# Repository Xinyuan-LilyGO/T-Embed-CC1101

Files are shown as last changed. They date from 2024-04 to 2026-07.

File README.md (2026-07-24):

<h1 align = "center">🏆T-Embed-CC1101🏆</h1>

* [切换到中文](./README_CN.md)



<p> 
  
  
  
</p>

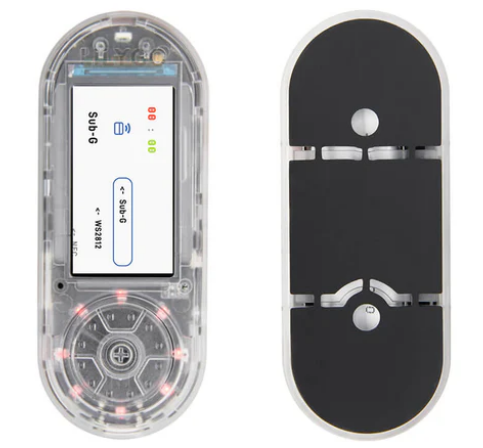
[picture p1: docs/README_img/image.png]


## :zero: Version 🎁

### 1、Latest version
- Software : v1.3-250822
- Hardware : v1.0-241103

### 2、Where to buy.
[LilyGo Store](https://www.lilygo.cc/products/t-embed-cc1101)

## :one: Product 🎁

Video about T-Embed-CC1101 :  [youtube](https://www.youtube.com/watch?v=U06XI1wtp4U) 

| Product | [T-Embed-CC1101 ](https://www.lilygo.cc/products/t-embed-cc1101) |
| :---: | :---: |
| MCU | ESP32-S3-WROOM-1 |
|  Flash / PSRAM | 16M / 8M |
| Sub-G | CC1101 |
| NFC | PN532 (0x24) |
| Display IC | ST7789 (320x170) |
| Battery Capacity | 3.7V-1300mAh |
| Battery Chip | BQ25896 (0x6B), BQ27220 (0x55) |
| LED Driver | WS2812 |

The charging current should ideally not exceed half of the battery capacity, and for the `T-Embed-CC1101`, it should not exceed `600mA`

External antenna 2.4G gains 1.5dBi, Sub1G antenna gain: -0.57dBi

Expansion module:

| - | NRF24 |
| :--- | :--- |
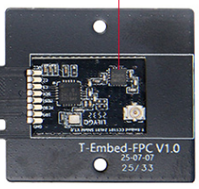
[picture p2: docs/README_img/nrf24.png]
| Module style |  |
| PIN | CS --- 44  <br>CE --- 43 <br>MOSI --- 9<br>MISO --- 10<br>SCK --- 11 |
| examples | [click me](./examples/extend_nrf2401) |

➡ Some interesting projects that support T-Embed-CC1101：

| name | code | web |
|:---:| :---: | :---: |
| Flipper Zero | [github](https://github.com/Sor3nt/Flipper-Zero-ESP32-Port "https://github.com/Sor3nt/Flipper-Zero-ESP32-Port") | [web](https://sor3nt.github.io/interface.html "https://sor3nt.github.io/interface.html") |
| Bruce | [github](https://github.com/pr3y/Bruce/tree/WebPage "https://github.com/pr3y/Bruce/tree/WebPage") | [web](https://bruce.computer/flasher.html "https://bruce.computer/flasher.html") |
| Launcher | [github](https://github.com/bmorcelli/M5Stick-Launcher.git "https://github.com/bmorcelli/M5Stick-Launcher.git") | [web](https://bmorcelli.github.io/Launcher/catalog.html) |
| CapibaraZero | [github](https://github.com/CapibaraZero/fw.git "https://github.com/CapibaraZero/fw.git") | [web](https://capibarazero.com/docs/esp32_s3/boards/LilyGo_T_Embed_CC1101) |

## :two: Module 🎁

Datasheets on the chip are available in [./hardware](./hardware/) directory.

| Name | Dependency library |
| :---: | :---: |
|  CC1101  | [jgromes/RadioLib@6.5.0](https://github.com/jgromes/RadioLib) |
|  PN532 | https://github.com/Seeed-Studio/PN532.git |
| BQ25896  | [lewisxhe/XPowersLib@^0.2.3](https://github.com/lewisxhe/XPowersLib) |
|  ST7789  | [bodmer/TFT_eSPI@^2.5.43](https://github.com/Bodmer/TFT_eSPI) |
|  Encode  | [mathertel/RotaryEncoder@^1.5.3](http://www.mathertel.de/Arduino/RotaryEncoderLibrary.aspx) |
|  WS2812  | [fastled/FastLED@^3.9.12](https://github.com/FastLED/FastLED) |
| Infrared | [crankyoldgit/IRremoteESP8266@^2.8.6](https://github.com/crankyoldgit/IRremoteESP8266) |
|  Audio | [esphome/ESP32-audioI2S@2.0.0](https://github.com/schreibfaul1/ESP32-audioI2S) |
| LVGL | [lvgl/lvgl@^8.3.11](https://github.com/lvgl/lvgl/tree/v8.3.11) |
### 1、Wireless transceiver：

T-Embed-CC1101 has a built-in Sub-GHz module based on a `CC1101` transceiver and a radio antenna (the maximum range is 50 meters).  Both the CC1101 chip and the antenna are designed to operate at frequencies in the 300-348 MHz, 387-464 MHz, and 779-928 MHz bands.

The Sub-GHz application supports external radio modules based on the CC1101 transceiver.

Notice : The frequency selection of CC1101 is configured through `SW0` and `SW1`.
~~~c
// SW1:1  SW0:0 --- 315MHz
// SW1:0  SW0:1 --- 868/915MHz
// SW1:1  SW0:1 --- 434MHz
#define BOARD_LORA_SW1  47
#define BOARD_LORA_SW0  48
~~~
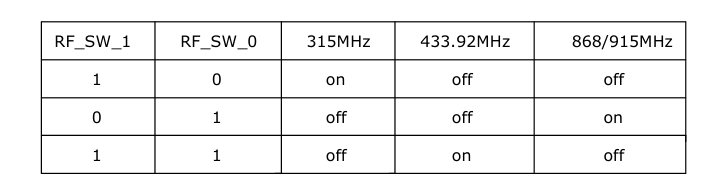
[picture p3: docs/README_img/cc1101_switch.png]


### 2、PN532

The PN532 only supports high-frequency cards at 13.56MHz, does not support low-frequency cards at 125K, does not support CPU cards, and does not support encryption cards.

"✅" represents a card of support.
| **Type** | **Encryption Method** | **Anti-Copy Capability** | **Attack Risk** | Typical uses |
| :---: | :---: | :---: | :---: | :---: |
| **Mifare Classic** ✅ | Weak (CRYPTO1 algorithm, cracked) | Low | Easily cloned (e.g., via Proxmark3 tools) | Access control cards, public transportation cards (old system) |
| **NTAG**  ✅ | No encryption (UID lockable) | Very Low | Data can be arbitrarily read | Smart labels, advertising interaction, and product anti-counterfeiting |
| **Mifare Plus** | AES-128 encryption | Medium-High | Requires physical access to crack | - |
| **Felica** |  Dynamic encryption (SAM module)  | High | Hard to crack (Japan-exclusive protocol) | Japanese transportation cards, electronic wallets |
| **DESFire** | AES/TDES encryption | Very High | Supports multi-app isolation, resists side-channel attacks | High-security access control, campus one-card, electronic passport |
| **CPU Card** | Hardware encryption (SM4/ECC/RSA) | Very High | Supports China's national cryptographic standards, financial-grade security | Bank card, ID card, social security card |

## :three: Quick Start 🎁

🟢 PlatformIO is recommended because these examples were developed on it. 🟢 

### 1、PlatformIO

1. Install [Visual Studio Code](https://code.visualstudio.com/) and [Python](https://www.python.org/), and clone or download the project;
2. Search for the `PlatformIO` plugin in the `VisualStudioCode` extension and install it;
3. After the installation is complete, you need to restart `VisualStudioCode`
4. After opening this project, PlatformIO will automatically download the required tripartite libraries and dependencies, the first time this process is relatively long, please wait patiently;
5. After all the dependencies are installed, you can open the `platformio.ini` configuration file, uncomment in `example` to select a routine, and then press `ctrl+s` to save the `.ini` configuration file;
6. Click :ballot_box_with_check: under VScode to compile the project, then plug in USB and select COM under VScode;
7. Finally, click the :arrow_right:  button to download the program to Flash;

### 2、Arduino IDE

1. Install [Arduino IDE](https://www.arduino.cc/en/software)

2. Copy all files under `this project/lib/` and paste them into the Arduion library path (generally `C:\Users\YourName\Documents\Arduino\libraries`);

3. Open the Arduion IDE and click `File->Open` in the upper left corner to open an example in `this project/example/xxx/xxx.ino` under this item;

4. Then configure Arduion. After the configuration is completed in the following way, you can click the button in the upper left corner of Arduion to compile and download;

| Arduino IDE Setting | Value |
| --- | --- |
| Board | **ESP32S3 Dev Module** |
| Port | Your port |
| USB CDC On Boot | Enable |
| CPU Frequency | 240MHZ(WiFi) |
| Core Debug Level | None |
| USB DFU On Boot | Disable |
| Erase All Flash Before Sketch Upload | Disable |
| Events Run On | Core1 |
| Flash Mode | QIO 80MHZ |
| Flash Size | **16MB(128Mb)** |
| Arduino Runs On | Core1 |
| USB Firmware MSC On Boot | Disable |
| Partition Scheme | **16M Flash(3M APP/9.9MB FATFS)** |
| PSRAM | **OPI PSRAM** |
| Upload Mode | **UART0/Hardware CDC** |
| Upload Speed | 921600 |
| USB Mode | **CDC and JTAG** |

### 3、Folder structure:
~~~
├─3D_files: Store 3D structure files
├─boards  : Some information about the board for the platformio.ini configuration project;
├─data    : Picture resources used by the program;
├─example : Some examples;
├─firmare : `factory` compiled firmware;
├─hardware: Schematic diagram of the board, chip data;
├─lib     : Libraries used in the project;
~~~

### 4、Examples

~~~
- ✅ bq27xxx_test : BQ27220 test.
- ✅ bq25896_test : Battery management test. Print the battery status in the serial port.
- ✅ cc1101_recv_irq ：Wireless reception test, display received messages in the serial port.
- ✅ cc1101_send_irq ：Wireless sending test, display sent messages in the serial port.
- ✅ display_test ：Screen display test;
- ✅ encode_test ：encoder tester
- ✅ factory_test ：Factory programs can currently only be compiled and downloaded on PlatformIO;
- ✅ infrared_recv_test: Infrared test
- ✅ infrared_send_test: Infrared test
- ✅ lvgl_test ：lvgl benchmark and stress testing;
- ✅ pn532_test ：NFC test, display the IC card information in the serial port.
- ✅ tf_card_test ：SD card test, the file name is displayed in the serial port.
- ✅ record_test : Record 15 seconds of audio and save it to your SD card.
- ✅ voice_test : Loudspeaker test, read audio from SPIFFS.
- ✅ ble_uart_pairing : BLE UART pairing/status demo with on-screen passkey, bonding, connection state, and text echo. This is BLE GATT UART, not A2DP audio.
- ✅ ws2812_test ：LED light test;
~~~

## :four: Pins 🎁

~~~c
#define BOARD_USER_KEY 6
#define BOARD_PWR_EN   15

// WS2812
#define WS2812_NUM_LEDS 8
#define WS2812_DATA_PIN 14

// IR
#define BOARD_IR_EN 2
#define BOARD_IR_RX 1

// MIC
#define BOARD_MIC_DATA 42
#define BOARD_MIC_CLK  39

// VOICE
#define BOARD_VOICE_BCLK  46
#define BOARD_VOICE_LRCLK 40
#define BOARD_VOICE_DIN   7

// --------- DISPLAY ---------
// About LCD definition in the file: lib/TFT_eSPI/User_Setups/Setup214_LilyGo_T_Embed_PN532.h
#define DISPLAY_WIDTH  170
#define DISPLAY_HEIGHT 320

#define DISPLAY_BL   21 
#define DISPLAY_CS   41
#define DISPLAY_MISO 10
#define DISPLAY_MOSI  9
#define DISPLAY_SCLK 11
#define DISPLAY_DC   16
#define DISPLAY_RST  -1

// --------- ENCODER ---------
#define ENCODER_INA 4
#define ENCODER_INB 5
#define ENCODER_KEY 0

// --------- IIC ---------
#define BOARD_I2C_SDA  8
#define BOARD_I2C_SCL  18

// IIC addr
#define BOARD_I2C_ADDR_1 0x24  // PN532
#define BOARD_I2C_ADDR_2 0x55  // BQ27220
#define BOARD_I2C_ADDR_3 0x6b  // BQ25896

// NFC
#define BOARD_PN532_SCL     BOARD_I2C_SCL
#define BOARD_PN532_SDA     BOARD_I2C_SDA
#define BOARD_PN532_RF_REST 45
#define BOARD_PN532_IRQ     17

// --------- SPI ---------
#define BOARD_SPI_SCK  11
#define BOARD_SPI_MOSI 9
#define BOARD_SPI_MISO 10

// TF card
#define BOARD_SD_CS   13
#define BOARD_SD_SCK  BOARD_SPI_SCK
#define BOARD_SD_MOSI BOARD_SPI_MOSI
#define BOARD_SD_MISO BOARD_SPI_MISO

// LORA
#define BOARD_LORA_CS   12
#define BOARD_LORA_SCK  BOARD_SPI_SCK
#define BOARD_LORA_MOSI BOARD_SPI_MOSI
#define BOARD_LORA_MISO BOARD_SPI_MISO
#define BOARD_LORA_IO2  38
#define BOARD_LORA_IO0  3
#define BOARD_LORA_SW1  47
#define BOARD_LORA_SW0  48
~~~

### Extension interface

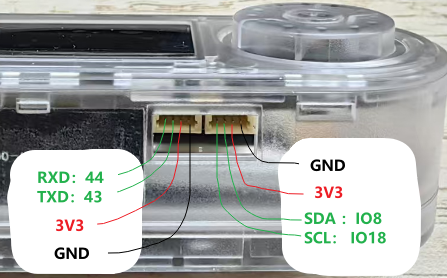
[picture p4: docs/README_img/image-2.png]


## :five: Test 🎁

Sleep power consumption.

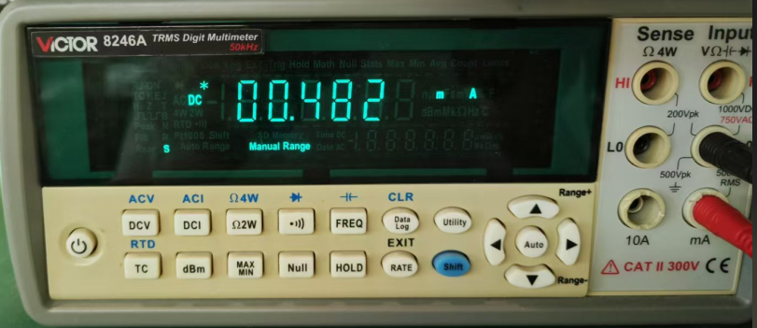
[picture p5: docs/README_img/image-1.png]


## :six: FAQ 🎁

### Unable to detect sd card：
We were able to successfully test SD with SanDisk no larger than 32GB; But some other cards don't, and it's not clear why;

Therefore, when the SD card is not detected, it is recommended to change a SanDisk card not larger than 32G;

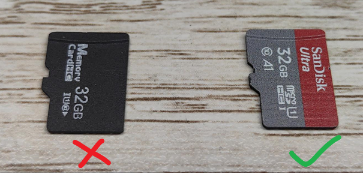
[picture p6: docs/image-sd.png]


### Other questions

| Problem | Link |
| :---: | :---: |
| How do I enter download mode? | [docs](./docs/download_mode.md) |
| How to download the program? | [dosc](./docs/flash_download_tool.md) |
|  How do I turn on the device after I shut it down?  | [Issues #5](https://github.com/Xinyuan-LilyGO/T-Embed-CC1101/issues/5) |
|      How do I configure Wifi with EspTouch?         | [Issues #4](https://github.com/Xinyuan-LilyGO/T-Embed-CC1101/issues/4) |
| Why won't the battery charge？ | [Issues #9](https://github.com/Xinyuan-LilyGO/T-Embed-CC1101/issues/9) |
| no display on the screen | [dosc](./docs/issue.md) |

## :seven: Schematic & 3D 🎁

For more information, see the `./hardware` directory.

Schematic : [T-Embed-CC1101](./hardware/T-Embed-CC1101%20V1.0%2024-07-29.pdf)

CC1101 Schematic : [CC1101](./hardware/cc1101-shield.pdf)

CC1101 Pins : [CC1101 Pins](./hardware/CC1101_pin.png)

3D Files : [T-Embed CC1101.stp](./3D_files)

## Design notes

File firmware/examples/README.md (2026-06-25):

# [中文](./README_CN.md) | English

# `firmware/examples/` Usage Guide

The `firmware/examples/` directory stores flashable example firmware generated from `examples/`.

Each build now exports only one merged `.bin` file directly into this directory. A typical structure looks like this:

```text
firmware/examples/
  README.md
  README_CN.md
  factory.bin
  test_ir_send_recv.bin
  test_cc1101_send_recv.bin
```

## 1. Which file should I use

Use the example-named `.bin` file directly, for example:

- `factory.bin`
- `test_ir_send_recv.bin`
- `test_cc1101_send_recv.bin`

Each file is a fully merged firmware image and should be flashed at address `0x0`.

## 2. How to flash

Example:

```powershell
python script\esptool.py --chip esp32s3 --baud 921600 write_flash -z 0x0 firmware\examples\test_ir_send_recv.bin
```

If `esptool` is already installed on your system, you can also use `esptool.py` directly or `python -m esptool`.

## 3. How to switch to another example

To test another example, flash that example's `.bin` file from `firmware/examples/`.

Examples:

- IR example: `firmware/examples/test_ir_send_recv.bin`
- CC1101 example: `firmware/examples/test_cc1101_send_recv.bin`
- Battery example: `firmware/examples/test_battery_bq27220_bq25896.bin`

## 4. Notes

- Make sure the device is in a downloadable state and the USB/serial connection is working before flashing.
- These firmware files are generated for this project's hardware configuration and should not be assumed to work on other boards.
- Some test examples are intended to be used together with serial logs, such as IR, wireless, battery, or NFC-related tests.
- Rebuilding the same example overwrites `firmware/examples/<example>.bin`.
- If an example path contains subfolders, the output filename uses `__` in place of `/`.
  For example, `extend_nrf2401/recv` becomes `extend_nrf2401__recv.bin`.

## 5. How to regenerate these files

Use the build script from the project root:

```powershell
python script\build_example_firmware.py --list
python script\build_example_firmware.py test_ir_send_recv
python script\build_example_firmware.py test_ir_send_recv test_cc1101_send_recv
python script\build_example_firmware.py --all
```

After the build completes, the generated `.bin` files will be placed in `firmware/examples/`.

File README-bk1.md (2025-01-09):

<h1 align = "center">🏆T-Embed-CC1101🏆</h1>



<p> 
  
  
  
</p>

<!-- * [切换到中文版](./README_CN.md) -->

## :zero: Troubleshooting

Video about T-Embed-CC1101 :  [youtube](https://www.youtube.com/watch?v=U06XI1wtp4U) 

| Problem | Link |
| :---: | :---: |
| How do I enter download mode? | [docs](./docs/download_mode.md) |
| How to download the program? | [dosc](./docs/flash_download_tool.md) |
|  How do I turn on the device after I shut it down?  | [Issues #5](https://github.com/Xinyuan-LilyGO/T-Embed-CC1101/issues/5) |
|      How do I configure Wifi with EspTouch?         | [Issues #4](https://github.com/Xinyuan-LilyGO/T-Embed-CC1101/issues/4) |
| Why won't the battery charge？ | [Issues #9](https://github.com/Xinyuan-LilyGO/T-Embed-CC1101/issues/9) |

## :one:Product 🎁

| Product | [T-Embed-CC1101 ](https://www.lilygo.cc/products/t-embed-cc1101) |
| :---: | :---: |
| MCU | ESP32-S3-WROOM-1 |
|  Flash / PSRAM | 16M / 8M |
| Sub-G | CC1101 |
| NFC | PN532 |
| Display IC | ST7789 (320x170) |
| Battery Capacity | 3.7V-1300mAh |
| Battery Chip | BQ25896, BQ27220 |
| LED Driver | WS2812 |

### About SD Card：
We were able to successfully test SD with SanDisk no larger than 32GB; But some other cards don't, and it's not clear why;

Therefore, when the SD card is not detected, it is recommended to change a SanDisk card not larger than 32G;



### Wireless transceiver：

T-Embed-CC1101 has a built-in Sub-GHz module based on a `CC1101` transceiver and a radio antenna (the maximum range is 50 meters). Both the CC1101 chip and the antenna are designed to operate at frequencies in the 300-348 MHz, 387-464 MHz, and 779-928 MHz bands.

The Sub-GHz application supports external radio modules based on the CC1101 transceiver.

### Folder structure:
~~~
├─boards  : Some information about the board for the platformio.ini configuration project;
├─data    : Picture resources used by the program;
├─example : Some examples;
├─firmare : `factory` compiled firmware;
├─hardware: Schematic diagram of the board, chip data;
├─lib     : Libraries used in the project;
~~~

## :two: Example 🎯

Some examples are provided under the Project example folder, which can run on PlatformIO (PIO) and Arduion, but I prefer to use PIO because these examples are developed on PIO, **All examples can run on PIO**, However, you may encounter compilation errors on Arduion, but don't worry, the author will step up to test the compilation of Arduion environment.

**Examples of compilation in Arduion environment:**

- ✅ bq25896_test : Battery management test. Print the battery status in the serial port.
- ✅ cc1101_recv_irq ：Wireless reception test, display received messages in the serial port.
- ✅ cc1101_send_irq ：Wireless sending test, display sent messages in the serial port.
- ✅ display_test ：Screen display test;
- ✅ encode_test ：encoder tester
- ❌ factory_test ：Factory programs can currently only be compiled and downloaded on PlatformIO;
- ✅ infrared_recv_test: Infrared test
- ✅ infrared_send_test: Infrared test
- ✅ lvgl_test ：lvgl benchmark and stress testing;
- ✅ pn532_test ：NFC test, display the IC card information in the serial port.
- ✅ tf_card_test ：SD card test, the file name is displayed in the serial port.
- ✅ record_test : Record 15 seconds of audio and save it to your SD card.
- ✅ voice_test : Speaker test, read audio from SD card.
- ✅ ws2812_test ：LED light test;

## :three: PlatformIO Quick Start

1. Install [Visual Studio Code](https://code.visualstudio.com/) and [Python](https://www.python.org/), and clone or download the project;
2. Search for the `PlatformIO` plugin in the `VisualStudioCode` extension and install it;
3. After the installation is complete, you need to restart `VisualStudioCode`
4. After opening this project, PlatformIO will automatically download the required tripartite libraries and dependencies, the first time this process is relatively long, please wait patiently;
5. After all the dependencies are installed, you can open the `platformio.ini` configuration file, uncomment in `example` to select a routine, and then press `ctrl+s` to save the `.ini` configuration file;
6. Click :ballot_box_with_check: under VScode to compile the project, then plug in USB and select COM under VScode;
7. Finally, click the :arrow_right:  button to download the program to Flash;

## :four: Arduion Quick Start

:exclamation: :exclamation: :exclamation: <font color="red"> **Notice:**</font>
PlatformIO is more recommended because it may not be compiled with Arduion. You can refer to **2️⃣-Example** to see which examples are successfully compiled in Arduion environment.

1. Install [Arduino IDE](https://www.arduino.cc/en/software)
2. Install the esp32 toolkit, open the Arduion IDE, click on `File->Perferences`, Then `https://espressif.github.io/arduino-esp32/package_esp32_index.json ` paste to the position of the diagram below, then click :ok:, waiting for the toolkit download is complete;

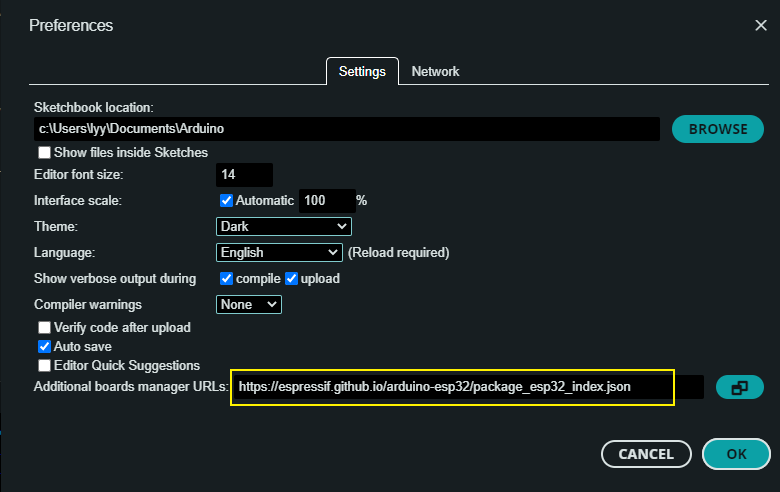
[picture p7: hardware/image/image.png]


3. Copy all files under `this project/lib/` and paste them into the Arduion library path (generally `C:\Users\YourName\Documents\Arduino\libraries`);
4. Open the Arduion IDE and click `File->Open` in the upper left corner to open an example in `this project/example/xxx/xxx.ino` under this item;
5. Then configure Arduion. After the configuration is completed in the following way, you can click the button in the upper left corner of Arduion to compile and download;

| Arduino IDE Setting | Value |
| --- | --- |
| Board | **ESP32S3 Dev Module** |
| Port | Your port |
| USB CDC On Boot | Enable |
| CPU Frequency | 240MHZ(WiFi) |
| Core Debug Level | None |
| USB DFU On Boot | Disable |
| Erase All Flash Before Sketch Upload | Disable |
| Events Run On | Core1 |
| Flash Mode | QIO 80MHZ |
| Flash Size | **16MB(128Mb)** |
| Arduino Runs On | Core1 |
| USB Firmware MSC On Boot | Disable |
| Partition Scheme | **16M Flash(3M APP/9.9MB FATFS)** |
| PSRAM | **OPI PSRAM** |
| Upload Mode | **UART0/Hardware CDC** |
| Upload Speed | 921600 |
| USB Mode | **CDC and JTAG** |

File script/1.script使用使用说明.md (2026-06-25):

# 自动打包工具

- **pos_extra_script.py** 将编译生成的 boot.bin、bootload.bin、partition.bin 打包生成一个 bin 文件；

应用举例：在 platformIO 的环境中，找到 platformio.ini 配置文件，在配置文件关于工程的默认环境下，添加该脚本，如下：

~~~
...

[env]
platform = espressif32@6.3.0
framework = arduino
upload_speed = 115200
...
extra_scripts =  ./script/pos_extra_script.py
...
~~~

如上所示，在添加 extra_scripts 后，在编译整个工程，编译完成后会自动调用 pos_extra_script.py 脚本生成 firmware_factory_xxxxxxxx.bin 固件；

如果该工程下还有 data 文件夹，则会自动的把 data 文件识别为 spiffs 文件系统，并将 data 文件夹下的所有文件打包成 spiffs.bin，还会自动生成 partitions.csv 文件；

**pos_extra_script.py 生成的所有文件都会放在 "工程目录/build/" 下面；**

# SPIFFS 文件系统

SPIFFS 是一个用于 SPI NOR flash 设备的嵌入式文件系统，支持磨损均衡、文件系统一致性检查等功能。

- **spiffsgen.py** 文件系统打包脚本

~~~ python
python spiffsgen.py <image_size> <base_dir> <output_file>

参数（必选）说明如下：
image_size：分区大小，用于烧录生成的 SPIFFS 镜像；
base_dir：创建 SPIFFS 镜像的目录；
output_file：SPIFFS 镜像输出文件。
~~~

应用举例：将工程 T-Embed-PN532 文件下的 data 文件打包，生成的 .bin 文件放到 build 文件夹下，则因向命令行输入如下命令：

~~~ python
python spiffsgen.py 0x360000 ..\data\ ..\build\spiffs.bin
~~~

## build_example_firmware

作用是从 `examples/` 里选示例编译，并把可下载的固件文件导出到 `firmware/examples/<示例名>/bin/`。

最常用的几种命令是：

列出所有可构建示例。
~~~powershell
python script\build_example_firmware.py --list
~~~

构建单个示例。
~~~powershell
python script\build_example_firmware.py test_ir_send_recv
~~~

一次构建多个示例。
~~~powershell
python script\build_example_firmware.py test_ir_send_recv test_ws2812
~~~

一次构建 examples/ 下全部示例。
~~~powershell
python script\build_example_firmware.py --all
~~~

可选参数：
~~~powershell
python script\build_example_firmware.py test_ir_send_recv --no-clean
python script\build_example_firmware.py test_ir_send_recv --no-merge
python script\build_example_firmware.py --all --continue-on-error
~~~

参数说明：
- `--no-clean`：跳过构建前清理，加快二次编译
- `--no-merge`：不生成合并后的单文件 bin
- `--continue-on-error`：某个示例失败后继续构建后面的示例
- `--env T_Embed_CC1101`：指定 PlatformIO 环境
- `--chip esp32s3`：指定烧录命令里的芯片型号

构建完成后，输出目录类似：
~~~powershell
firmware\examples\test_ir_send_recv\bin\
~~~

里面通常会有：
- `bootloader.bin`
- `partitions.bin`
- `firmware.bin`
- `test_ir_send_recv.bin` 这是合并后的单文件固件
- `esptool_command.txt`
- `esptool_merged_command.txt`
- `build_info.json`

如果你想直接烧录合并包，可以看对应目录下的 `esptool_merged_command.txt`。
补一句，最好不要同时开两个 `build_example_firmware.py` 进程，因为它们会共用 `.pio/build/T_Embed_CC1101`。

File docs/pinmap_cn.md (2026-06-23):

# T-Embed-CC1101 引脚映射（V1.0 / 2026-06-23）
> 本文根据 `hardware/T-Embed-CC1101 V1.0 24-07-29.pdf`、`README.md`、`README_CN.md`、`examples/factory_test/utilities.h`、`docs/README_img/image-2.png` 整理。
> 仓库里的部分宏名沿用了旧命名：`BOARD_LORA_*` 实际对应板载 `CC1101`，`BOARD_PN532_*` 对应板载 `PN532`。
> 需要先说明：当前仓库里有两处定义不完全一致。其一是个别示例把 I2C `SDA/SCL` 写反；其二是 LCD `RST` 在原理图与软件配置之间存在歧义。文中会单独标注。

## 1. 主控与公共总线

| 功能 | 建议名 | GPIO/映射 | 来源 | 备注 |
| --- | --- | --- | --- | --- |
| 主 I2C SDA | `BOARD_I2C_SDA` | GPIO8 | 原理图 Page 1/2/3/4，`docs/README_img/image-2.png`，`examples/factory_test/utilities.h` | 板载 PN532、BQ27220、BQ25896 与外接 I2C 口共用；`examples/cc1101_recv/utilities.h` 把 SDA/SCL 对调了，建议以本表为准 |
| 主 I2C SCL | `BOARD_I2C_SCL` | GPIO18 | 原理图 Page 1/2/3/4，`docs/README_img/image-2.png`，`examples/factory_test/utilities.h` | 同上 |
| 主 SPI SCK | `BOARD_SPI_SCK` | GPIO11 | 原理图 Page 2/3/4，`examples/factory_test/utilities.h` | LCD、TF、PN532、CC1101、外接 nRF24 共用 |
| 主 SPI MOSI | `BOARD_SPI_MOSI` | GPIO9 | 原理图 Page 2/3/4，`examples/factory_test/utilities.h` | 同上 |
| 主 SPI MISO | `BOARD_SPI_MISO` | GPIO10 | 原理图 Page 2/3/4，`examples/factory_test/utilities.h` | 同上 |
| 开关 3.3 V 使能 | `BOARD_PWR_EN` | GPIO15 | 原理图 Page 1/2，`README.md`，`examples/factory_test/utilities.h` | 控制开关电源域 `VCC3V3`；仓库示例注释明确写到会给 CC1101 与 WS2812/LED 上电 |
| USB D- | `BOARD_USB_DM` | GPIO19 | 原理图 Page 1/2 | Type-C 直连 ESP32-S3 USB |
| USB D+ | `BOARD_USB_DP` | GPIO20 | 原理图 Page 1/2 | Type-C 直连 ESP32-S3 USB |
| 串口调试 TX | `BOARD_UART0_TXD` | `U0TXD` / GPIO43 | 原理图 Page 2，`docs/README_img/image-2.png` | 外接接口图片标成 `TXD: 43`；扩展 nRF24 示例中也把这脚复用为 `CE` |
| 串口调试 RX | `BOARD_UART0_RXD` | `U0RXD` / GPIO44 | 原理图 Page 2，`docs/README_img/image-2.png` | 外接接口图片标成 `RXD: 44`；扩展 nRF24 示例中也把这脚复用为 `CS` |

## 2. 按键与编码器

| 功能 | 建议名 | GPIO/映射 | 来源 | 备注 |
| --- | --- | --- | --- | --- |
| 用户按键 | `BOARD_USER_KEY` | GPIO6 | 原理图 Page 2，`README.md`，`examples/factory_test/utilities.h` | 独立按键 |
| 编码器 A 相 | `ENCODER_INA` | GPIO4 | 原理图 Page 2/4，`examples/factory_test/utilities.h` | 旋钮编码器 A 相 |
| 编码器 B 相 | `ENCODER_INB` | GPIO5 | 原理图 Page 2/4，`examples/factory_test/utilities.h` | 旋钮编码器 B 相 |
| 编码器按压 / BOOT | `ENCODER_KEY` | GPIO0 | 原理图 Page 2/4，`examples/factory_test/utilities.h` | 既是编码器按键又是启动脚，低电平会影响下载/启动模式 |
| 复位按键 | `BOARD_RST_EN` | `EN` | 原理图 Page 2 | 复位按键，不是普通 GPIO |

## 3. 扩展接口与外接模块

| 接口/功能 | 建议名 | 引脚/网络 | 来源 | 备注 |
| --- | --- | --- | --- | --- |
| 外接 UART TX | `BOARD_UART0_TXD` | GPIO43 | 原理图 Page 2，`docs/README_img/image-2.png` | 与 3V3 / GND 一起引出 |
| 外接 UART RX | `BOARD_UART0_RXD` | GPIO44 | 原理图 Page 2，`docs/README_img/image-2.png` | 与 3V3 / GND 一起引出 |
| 外接 I2C SDA | `BOARD_I2C_SDA` | GPIO8 | 原理图 Page 2，`docs/README_img/image-2.png` | 与 3V3 / GND 一起引出 |
| 外接 I2C SCL | `BOARD_I2C_SCL` | GPIO18 | 原理图 Page 2，`docs/README_img/image-2.png` | 与 3V3 / GND 一起引出 |
| 外接 nRF24 CE | `BOARD_NRF24_CE` | GPIO43 | `examples/factory_test/utilities.h`，`examples/extend_nrf2401/*` | 只在外接模块场景使用；与外接 UART `TXD` 复用 |
| 外接 nRF24 CS | `BOARD_NRF24_CS` | GPIO44 | `examples/factory_test/utilities.h`，`examples/extend_nrf2401/*` | 只在外接模块场景使用；与外接 UART `RXD` 复用 |
| 外接 nRF24 SPI | `BOARD_NRF24_SCK/MOSI/MISO` | GPIO11 / 9 / 10 | `examples/factory_test/utilities.h`，`examples/extend_nrf2401/*` | 共享主 SPI |
| 外接 nRF24 IRQ | `BOARD_NRF24_IRQ` | `-1` | `examples/factory_test/utilities.h` | 当前仓库未给外接 nRF24 分配独立中断脚 |

## 4. TF 卡

| 功能 | 建议名 | GPIO | 来源 | 备注 |
| --- | --- | --- | --- | --- |
| SD CS | `BOARD_SD_CS` | GPIO13 | 原理图 Page 2，`examples/factory_test/utilities.h` | 共享主 SPI |
| SD SCK | `BOARD_SD_SCK` | GPIO11 | 原理图 Page 2，`examples/factory_test/utilities.h` | 共享主 SPI |
| SD MOSI | `BOARD_SD_MOSI` | GPIO9 | 原理图 Page 2，`examples/factory_test/utilities.h` | 共享主 SPI |
| SD MISO | `BOARD_SD_MISO` | GPIO10 | 原理图 Page 2，`examples/factory_test/utilities.h` | 共享主 SPI |

## 5. 音频与麦克风

| 功能 | 建议名 | GPIO/映射 | 来源 | 备注 |
| --- | --- | --- | --- | --- |
| I2S BCLK | `BOARD_VOICE_BCLK` | GPIO46 | 原理图 Page 2，`examples/factory_test/utilities.h` | ESP32-S3 -> MAX98357A |
| I2S LRCLK | `BOARD_VOICE_LRCLK` | GPIO40 | 原理图 Page 2，`examples/factory_test/utilities.h` | ESP32-S3 -> MAX98357A |
| I2S DIN | `BOARD_VOICE_DIN` | GPIO7 | 原理图 Page 2，`examples/factory_test/utilities.h` | ESP32-S3 -> MAX98357A |
| MIC DATA | `BOARD_MIC_DATA` | GPIO42 | 原理图 Page 2/4，`examples/factory_test/utilities.h` | 数字麦克风数据输入 |
| MIC CLK | `BOARD_MIC_CLK` | GPIO39 | 原理图 Page 2/4，`examples/factory_test/utilities.h` | 数字麦克风时钟 |
| 扬声器接口 | `BOARD_SPK_OUT` | `J4` | 原理图 Page 2 | 2 Pin 扬声器座，不是 GPIO |

## 6. PN532（NFC）

I2C 地址：`0x24`

| 功能 | 建议名 | GPIO/映射 | 来源 | 备注 |
| --- | --- | --- | --- | --- |
| I2C SDA | `BOARD_PN532_SDA` | GPIO8 | 原理图 Page 1/2/3/4，`examples/factory_test/utilities.h` | 与主 I2C 共用 |
| I2C SCL | `BOARD_PN532_SCL` | GPIO18 | 原理图 Page 1/2/3/4，`examples/factory_test/utilities.h` | 与主 I2C 共用 |
| RST / Power-Down | `BOARD_PN532_RF_REST` | GPIO45 | 原理图 Page 2/3，`examples/factory_test/utilities.h` | 原理图网名是 `RF_RST`，芯片脚名是 `RSTPD_N` |
| IRQ | `BOARD_PN532_IRQ` | GPIO17 | 原理图 Page 2/3，`examples/factory_test/utilities.h` | 原理图网名 `IRQ` |

## 7. CC1101（仓库中沿用 `LORA` 命名）

| 功能 | 建议名 | GPIO/映射 | 来源 | 备注 |
| --- | --- | --- | --- | --- |
| SPI SCK | `BOARD_LORA_SCK` | GPIO11 | 原理图 Page 2/3，`examples/factory_test/utilities.h` | 共享主 SPI |
| SPI MOSI | `BOARD_LORA_MOSI` | GPIO9 | 原理图 Page 2/3，`examples/factory_test/utilities.h` | 共享主 SPI |
| SPI MISO | `BOARD_LORA_MISO` | GPIO10 | 原理图 Page 2/3，`examples/factory_test/utilities.h` | 共享主 SPI |
| CS | `BOARD_LORA_CS` | GPIO12 | 原理图 Page 2/3，`examples/factory_test/utilities.h` | 原理图网名 `HPD_CS` |
| GDO2 | `BOARD_LORA_IO2` | GPIO38 | 原理图 Page 2/3，`examples/factory_test/utilities.h` | 原理图网名 `LORA_IO2` |
| GDO0 | `BOARD_LORA_IO0` | GPIO3 | 原理图 Page 2/3，`examples/factory_test/utilities.h` | 原理图网名 `LORA_IO0` |
| 射频开关 1 | `BOARD_LORA_SW1` | GPIO47 | 原理图 Page 2/3，`examples/factory_test/utilities.h` | 原理图网名 `SW_1` |
| 射频开关 0 | `BOARD_LORA_SW0` | GPIO48 | 原理图 Page 2/3，`examples/factory_test/utilities.h` | 原理图网名 `SW_0` |
| 供电域 | `BOARD_LORA_VDD` | `VCC3V3` | 原理图 Page 1/3 | 受 `BOARD_PWR_EN` 控制 |

CC1101 频段切换在仓库示例里约定如下：

- `SW1=1, SW0=0` -> `315 MHz`
- `SW1=1, SW0=1` -> `434 MHz`
- `SW1=0, SW0=1` -> `868 / 915 MHz`

以上映射来自 `examples/cc1101_send/cc1101_send.ino` 与 `examples/factory_test/ui.cpp`。

## 8. LCD 与背光

| 功能 | 建议名 | GPIO/映射 | 来源 | 备注 |
| --- | --- | --- | --- | --- |
| LCD CS | `DISPLAY_CS` | GPIO41 | 原理图 Page 2/4，`lib/TFT_eSPI/User_Setups/Setup214_LilyGo_T_Embed_PN532.h` | 原理图网名 `LCD_CS` |
| LCD DC | `DISPLAY_DC` | GPIO16 | 原理图 Page 2，`lib/TFT_eSPI/User_Setups/Setup214_LilyGo_T_Embed_PN532.h` | 原理图 Page 2 标成 `LCD_DC` |
| 背光使能 | `DISPLAY_BL` | GPIO21 | 原理图 Page 2/4，`lib/TFT_eSPI/User_Setups/Setup214_LilyGo_T_Embed_PN532.h` | 原理图网名 `BL_EN`，驱动芯片为 `AW9364` |
| SPI SCK | `DISPLAY_SCLK` | GPIO11 | 原理图 Page 2/4，`lib/TFT_eSPI/User_Setups/Setup214_LilyGo_T_Embed_PN532.h` | 共享主 SPI |
| SPI MOSI | `DISPLAY_MOSI` | GPIO9 | 原理图 Page 2/4，`lib/TFT_eSPI/User_Setups/Setup214_LilyGo_T_Embed_PN532.h` | 共享主 SPI |
| SPI MISO | `DISPLAY_MISO` | GPIO10 | 原理图 Page 2/4，`lib/TFT_eSPI/User_Setups/Setup214_LilyGo_T_Embed_PN532.h` | 共享主 SPI |
| LCD RST | `DISPLAY_RST` | `-1`（软件配置） | `lib/TFT_eSPI/User_Setups/Setup214_LilyGo_T_Embed_PN532.h`，原理图 Page 4 | 软件里没有单独控制 RST；原理图第 4 页文字提取又出现了 `LCD_RES -> IO40`，但仓库同时把 `IO40` 用作音频 `LRCLK`，这里视为“存在歧义，当前仓库未启用独立 LCD RST” |

补充说明：原理图第 4 页还出现 `T_RST -> IO46`、`T_INT -> IO16` 这类触摸相关标注，但当前仓库没有触摸驱动配置，而且 `IO46` / `IO16` 在软件里分别已经被音频 `BCLK` / `LCD_DC` 使用。后续如果要接入触摸，建议先重新核对实际屏模组与 FFC 引脚定义。

## 9. RGB 与红外

| 功能 | 建议名 | GPIO/映射 | 来源 | 备注 |
| --- | --- | --- | --- | --- |
| WS2812 数据 | `WS2812_DATA_PIN` | GPIO14 | 原理图 Page 2/4，`examples/factory_test/utilities.h` | 板上共有 `8` 颗 WS2812 |
| 红外发射使能 / PWM | `BOARD_IR_EN` | GPIO2 | 原理图 Page 2/4，`examples/factory_test/utilities.h` | 原理图网名 `IR_EN` |
| 红外接收 | `BOARD_IR_RX` | GPIO1 | 原理图 Page 2/4，`examples/factory_test/utilities.h` | 原理图网名 `IR_RX` |

## 10. I2C 地址表

| 设备 | 地址 | 来源 | 备注 |
| --- | --- | --- | --- |
| PN532 | `0x24` | `README.md`，`examples/factory_test/utilities.h` | NFC |
| BQ27220 | `0x55` | 原理图 Page 1，`README.md`，`examples/factory_test/utilities.h` | 电量计 |
| BQ25896 | `0x6B` | 原理图 Page 1，`README.md`，`examples/factory_test/utilities.h` | 充电管理 |

## 11. 命名与风险提示

- `BOARD_LORA_*` 这组宏在本板上实际服务的是 `CC1101`，如果后续做公共板级抽象，建议改成 `BOARD_CC1101_*` 一类更直观的命名。
- `BOARD_PWR_EN` 控制的是一个开关 3.3 V 电源域，不是“整机主电源键”；仓库里多个示例都把它当成 `CC1101/WS2812` 的上电开关。
- `examples/cc1101_recv/utilities.h` 中的 `BOARD_SDA_PIN` / `BOARD_SCL_PIN` 与仓库主定义相反，写新代码时建议统一使用 `GPIO8 = SDA`、`GPIO18 = SCL`。
- `GPIO43/44` 既被当作外接串口 `TXD/RXD`，也在外接 `nRF24L01` 示例中被复用成 `CE/CS`。如果你要同时接串口和外设，需要先明确复用策略。
- `Setup214_LilyGo_T_Embed_PN532.h` 这个文件名虽然带 `PN532`，但在当前仓库里承担的是 `T-Embed-CC1101` 的 LCD 配置，不要被文件名误导。
- 当前仓库的引脚定义散落在多个 `utilities.h` 和 README 片段里；如果后续继续扩展项目，建议收敛到单一 `board_pins.h` 或 `board_config.h`。

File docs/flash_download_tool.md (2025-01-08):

How to use the official software download program;

1、Download the `Flash Download Tools` , [Flash Download Tools](https://www.espressif.com/en/support/download/other-tools);

2、Plug in USB. T-Embed-CC1101 Enters download mode;
- :one: Press and hold the BOOT key in the middle of the encoder without releasing it

- :two: Click the RST button on the back and release

- :three: Finally, release the BOOT key

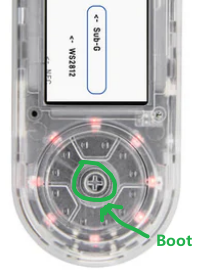
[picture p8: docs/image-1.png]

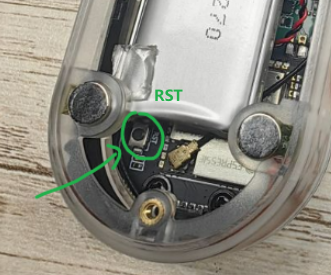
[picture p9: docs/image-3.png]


3、Open the `Flash Download Tools` tool and select from the following figure;

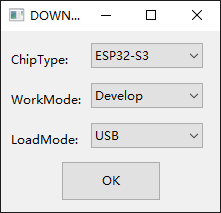
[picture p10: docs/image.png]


4、Select the program you want to download and click `Start` key to download it as shown in the image below;

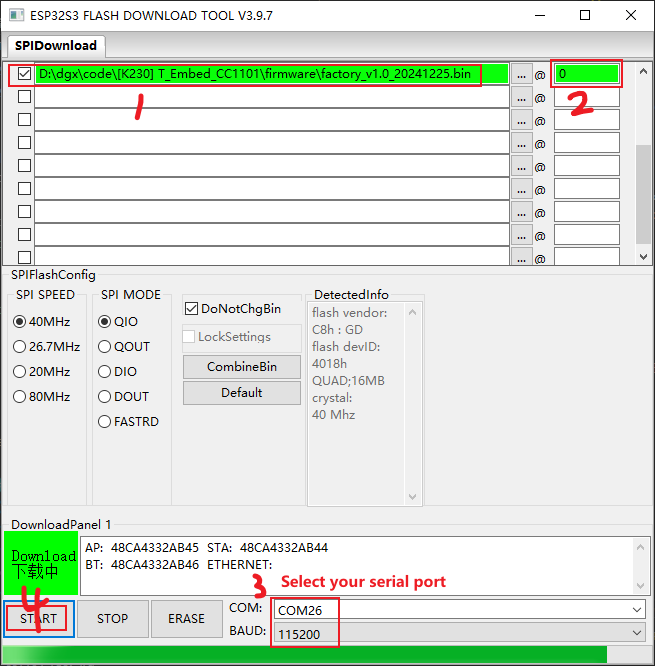
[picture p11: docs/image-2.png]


5、When the download is complete, click the `RST` button to restart the device;



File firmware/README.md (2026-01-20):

How to download the program? ->[dosc](../docs/flash_download_tool.md)

***Notice***: After the download is complete, if the screen does not light up, you need to press the `RST` key at the back;



---
There are also some firmware related to T-Embed-CC1101, which you can refer to via the link below.

| name | code | web |
| :---: | :---: | :---: |
| Bruce | [github](https://github.com/pr3y/Bruce/tree/WebPage "https://github.com/pr3y/Bruce/tree/WebPage") | [web](https://bruce.computer/flasher.html "https://bruce.computer/flasher.html") |
| Launcher | [github](https://github.com/bmorcelli/M5Stick-Launcher.git "https://github.com/bmorcelli/M5Stick-Launcher.git") | [web](https://bmorcelli.github.io/Launcher/catalog.html) |
| CapibaraZero | [github](https://github.com/CapibaraZero/fw.git "https://github.com/CapibaraZero/fw.git") | [web](https://capibarazero.com/docs/esp32_s3/boards/LilyGo_T_Embed_CC1101) |

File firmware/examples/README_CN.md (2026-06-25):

# 中文 | [English](./README.md)

# `firmware/examples/` 使用说明

`firmware/examples/` 目录用于存放从 `examples/` 构建出来、可直接烧录的示例固件。

现在每个示例只会导出一个合并好的 `.bin` 文件，并直接放到这个目录下面。常见结构如下：

```text
firmware/examples/
  README.md
  README_CN.md
  factory.bin
  test_ir_send_recv.bin
  test_cc1101_send_recv.bin
```

## 1. 推荐使用哪个文件

直接使用和示例同名的 `.bin` 文件即可，例如：

- `factory.bin`
- `test_ir_send_recv.bin`
- `test_cc1101_send_recv.bin`

这些文件都是已经合并好的完整固件，烧录时统一写入 `0x0` 地址。

## 2. 如何烧录

例如：

```powershell
python script\esptool.py --chip esp32s3 --baud 921600 write_flash -z 0x0 firmware\examples\test_ir_send_recv.bin
```

如果你已经安装了 `esptool`，也可以直接使用系统里的 `esptool.py` 或 `python -m esptool`。

## 3. 如何切换到另一个示例

如果想测试另一个示例，只需要重新烧录 `firmware/examples/` 下对应的 `.bin` 文件。

例如：

- 红外示例：`firmware/examples/test_ir_send_recv.bin`
- CC1101 示例：`firmware/examples/test_cc1101_send_recv.bin`
- 电池示例：`firmware/examples/test_battery_bq27220_bq25896.bin`

## 4. 注意事项

- 烧录前请确认设备处于可下载状态，串口和 USB 连接正常。
- 这些固件面向当前项目的硬件配置生成，不建议直接用于其他板型。
- 某些测试示例需要配合串口查看日志，例如红外、无线、电池或 NFC 类测试。
- 重新构建同一个示例时，会覆盖 `firmware/examples/<example>.bin`。
- 如果示例路径里带有子目录，输出文件名会把 `/` 替换成 `__`。
  例如 `extend_nrf2401/recv` 会生成 `extend_nrf2401__recv.bin`。

## 5. 如何重新生成这些文件

可以使用项目根目录下的构建脚本重新生成：

```powershell
python script\build_example_firmware.py --list
python script\build_example_firmware.py test_ir_send_recv
python script\build_example_firmware.py test_ir_send_recv test_cc1101_send_recv
python script\build_example_firmware.py --all
```

生成完成后，输出的 `.bin` 文件会放到 `firmware/examples/` 目录下。

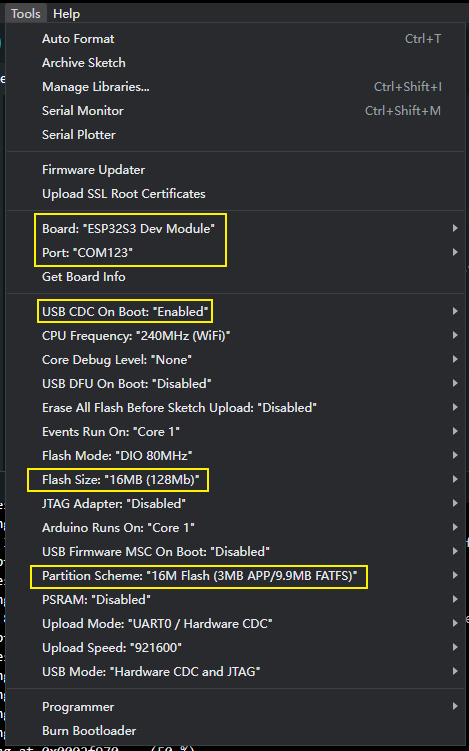
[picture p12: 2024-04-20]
hardware/image/Arduion_config_en.png

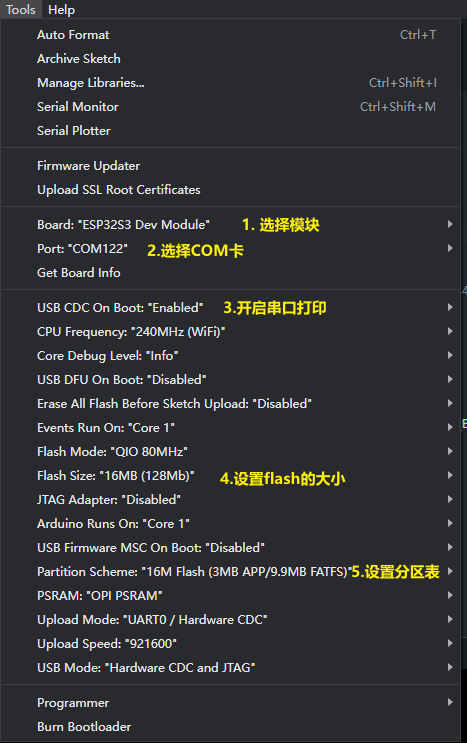
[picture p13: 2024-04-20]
hardware/image/Arduion_config.png

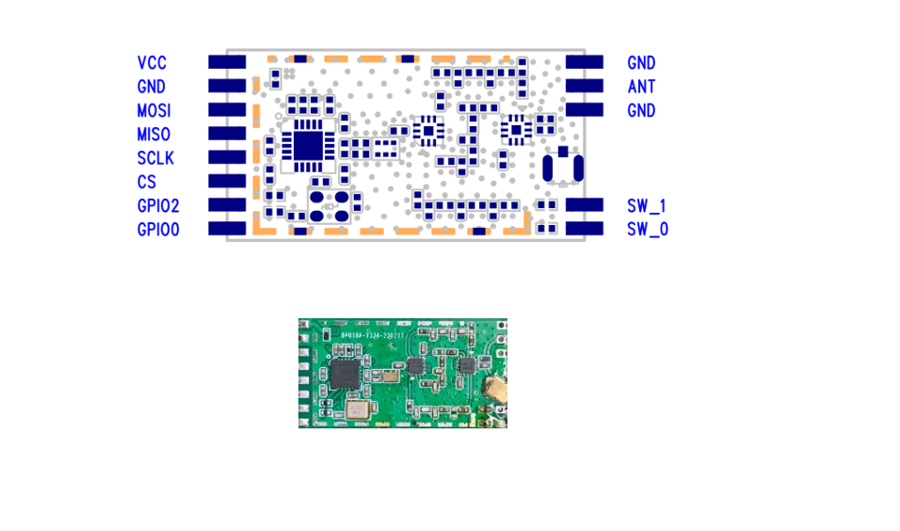
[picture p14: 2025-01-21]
hardware/CC1101_pin.png

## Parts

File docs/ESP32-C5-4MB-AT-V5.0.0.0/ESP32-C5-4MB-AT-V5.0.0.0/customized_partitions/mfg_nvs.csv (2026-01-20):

key | type | encoding | value
server_cert | namespace
server_cert | file | binary | /builds/application/esp-at/components/customized_partitions/raw_data/server_cert/server_cert.crt
server_key | namespace
server_key | file | binary | /builds/application/esp-at/components/customized_partitions/raw_data/server_key/server.key
server_ca | namespace
server_ca | file | binary | /builds/application/esp-at/components/customized_partitions/raw_data/server_ca/server_ca.crt
client_cert | namespace
client_cert.0 | file | binary | /builds/application/esp-at/components/customized_partitions/raw_data/client_cert/client_cert_00.crt
client_cert.1 | file | binary | /builds/application/esp-at/components/customized_partitions/raw_data/client_cert/client_cert_01.crt
client_key | namespace
client_key.0 | file | binary | /builds/application/esp-at/components/customized_partitions/raw_data/client_key/client_key_00.key
client_key.1 | file | binary | /builds/application/esp-at/components/customized_partitions/raw_data/client_key/client_key_01.key
client_ca | namespace
client_ca.0 | file | binary | /builds/application/esp-at/components/customized_partitions/raw_data/client_ca/client_ca_00.crt
client_ca.1 | file | binary | /builds/application/esp-at/components/customized_partitions/raw_data/client_ca/client_ca_01.crt
mqtt_cert | namespace
mqtt_cert | file | binary | /builds/application/esp-at/components/customized_partitions/raw_data/mqtt_cert/mqtt_client.crt
mqtt_key | namespace
mqtt_key | file | binary | /builds/application/esp-at/components/customized_partitions/raw_data/mqtt_key/mqtt_client.key
mqtt_ca | namespace
mqtt_ca | file | binary | /builds/application/esp-at/components/customized_partitions/raw_data/mqtt_ca/mqtt_ca.crt
factory_param | namespace
version | data | i8 | 4
module_name | data | string | ESP32C5-4MB
max_tx_power | data | i8 | 78
country_code | data | string | CN
start_channel | data | u8 | 1
channel_num | data | u8 | 13
uart_port | data | i8 | 1
uart_baudrate | data | i32 | 115200
uart_tx_pin | data | i32 | 23
uart_rx_pin | data | i32 | 24
uart_cts_pin | data | i32 | 25
uart_rts_pin | data | i32 | 26
sys_store | data | u8 | 1
ble_data | namespace
cfg0 | data | string | 0,16,0x2800,0x01,2,2,A002
cfg1 | data | string | 1,16,0x2803,0x01,1,1,02
cfg2 | data | string | 2,16,0xC300,0x01,1,1,30
cfg3 | data | string | 3,16,0x2901,0x11,1,1,30
cfg4 | data | string | 4,16,0x2803,0x01,1,1,02
cfg5 | data | string | 5,16,0xC301,0x01,512,512,
cfg6 | data | string | 6,16,0x2901,0x11,512,512,
cfg7 | data | string | 7,16,0x2803,0x01,1,1,08
cfg8 | data | string | 8,16,0xC302,0x10,1,1,30
cfg9 | data | string | 9,16,0x2901,0x01,1,1,01
cfg10 | data | string | 10,16,0x2803,0x01,1,1,04
cfg11 | data | string | 11,16,0xC303,0x10,1,1,30
cfg12 | data | string | 12,16,0x2901,0x10,1,1,30
cfg13 | data | string | 13,16,0x2803,0x01,1,1,08
cfg14 | data | string | 14,16,0xC304,0x10,512,512,
cfg15 | data | string | 15,16,0x2803,0x01,1,1,10
cfg16 | data | string | 16,16,0xC305,0x01,1,1,00
cfg17 | data | string | 17,16,0x2902,0x11,2,2,0000
cfg18 | data | string | 18,16,0x2803,0x01,1,1,20
cfg19 | data | string | 19,16,0xC306,0x01,1,1,00
cfg20 | data | string | 20,16,0x2902,0x11,2,2,0000
cfg21 | data | string | 21,16,0x2803,0x01,1,1,02
cfg22 | data | string | 22,16,0xC307,0x01,1,1,30
cfg23 | data | string | 23,16,0x2901,0x11,256,1,30
cfg24 | data | string | 24,16,0x2800,0x01,2,2,A003
cfg25 | data | string | 25,16,0x2803,0x01,1,1,02
cfg26 | data | string | 26,16,0xC400,0x01,1,1,30
cfg27 | data | string | 27,16,0x2901,0x11,1,1,30
cfg28 | data | string | 28,16,0x2803,0x01,1,1,02
cfg29 | data | string | 29,16,0xC401,0x01,1,1,30
cfg30 | data | string | 30,16,0x2901,0x11,256,1,30

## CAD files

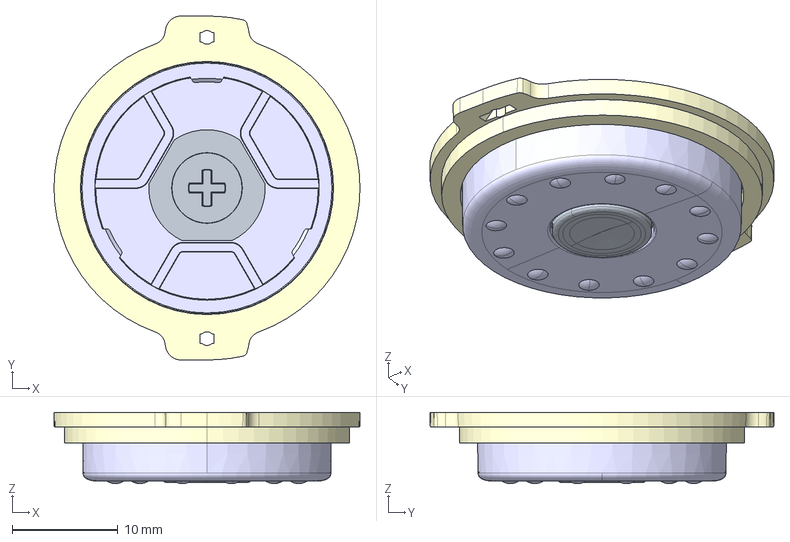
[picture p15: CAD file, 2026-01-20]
3D_files/0-bmq_asm.stp
29.0 x 32.6 x 6.75 mm
077-T_ENCODER_COV-A3_1_1
078-T_ENCODER_COV-B3_1_1
069_T-EMBED_COV-D00_1_3_1

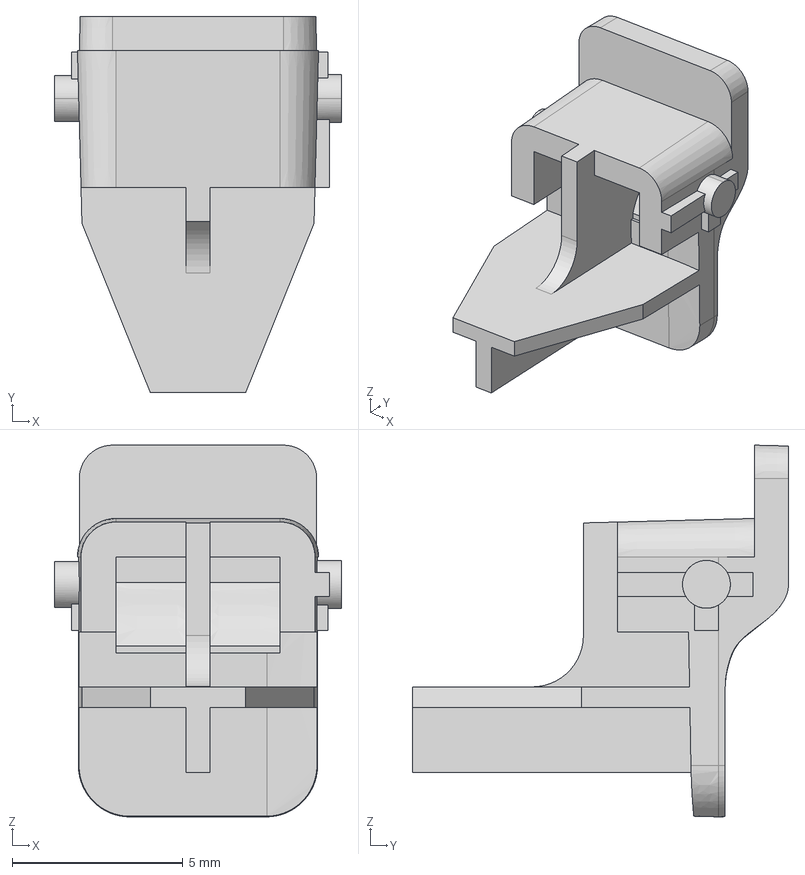
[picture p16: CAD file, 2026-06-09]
3D_files/K268-01-key01.stp
8.40 x 11.0 x 10.9 mm

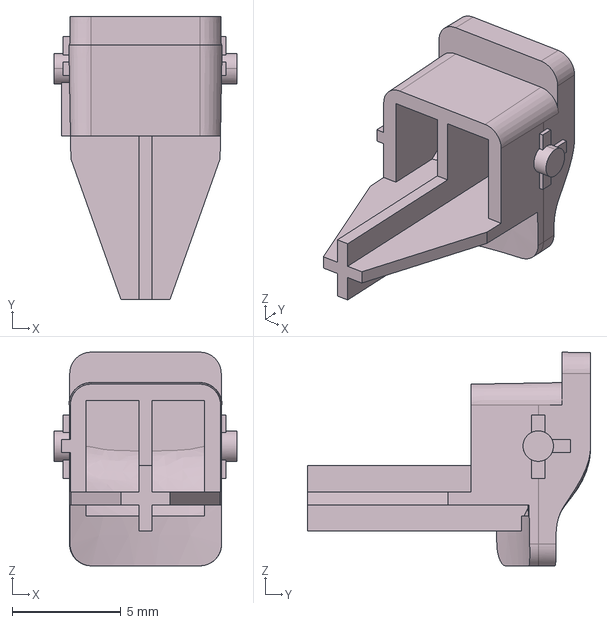
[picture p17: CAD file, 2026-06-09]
3D_files/K268-01-key02.stp
8.40 x 13.0 x 9.82 mm

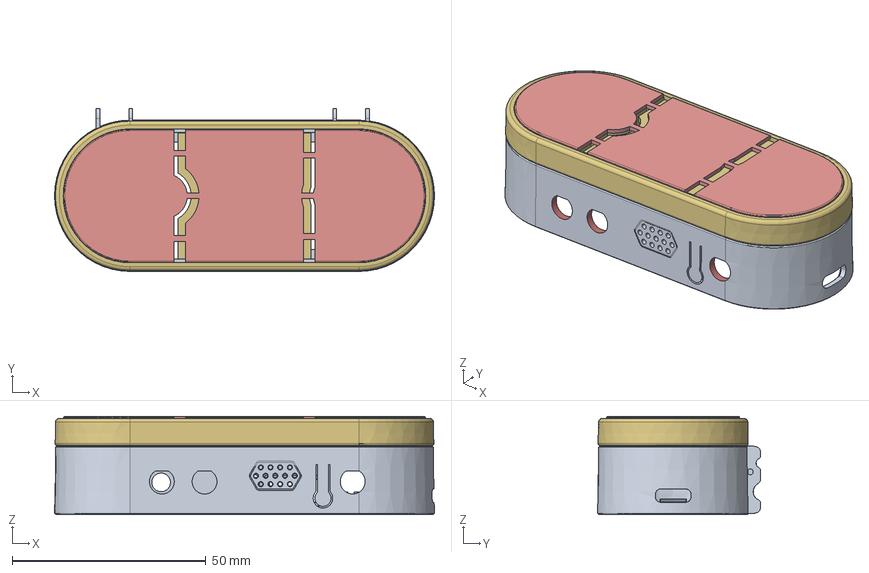
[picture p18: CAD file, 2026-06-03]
3D_files/external antenna.stp
98.0 x 42.0 x 25.3 mm
066_T-EMBED_COV-A5_3_20_74
T_EMBED-1_PCB_1_ASM_1_ASM_1_ASM

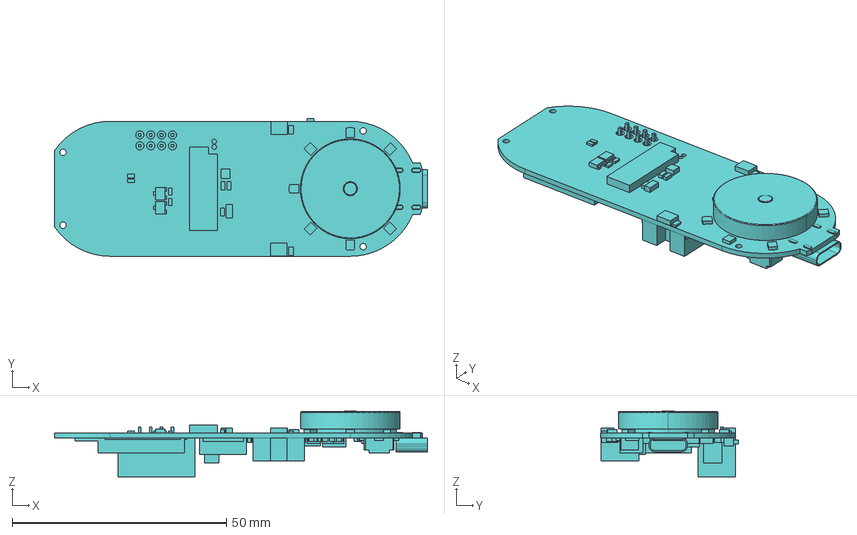
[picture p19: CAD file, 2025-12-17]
3D_files/t_embed-1_pcb_1_1_1.stp
87.0 x 32.1 x 15.3 mm

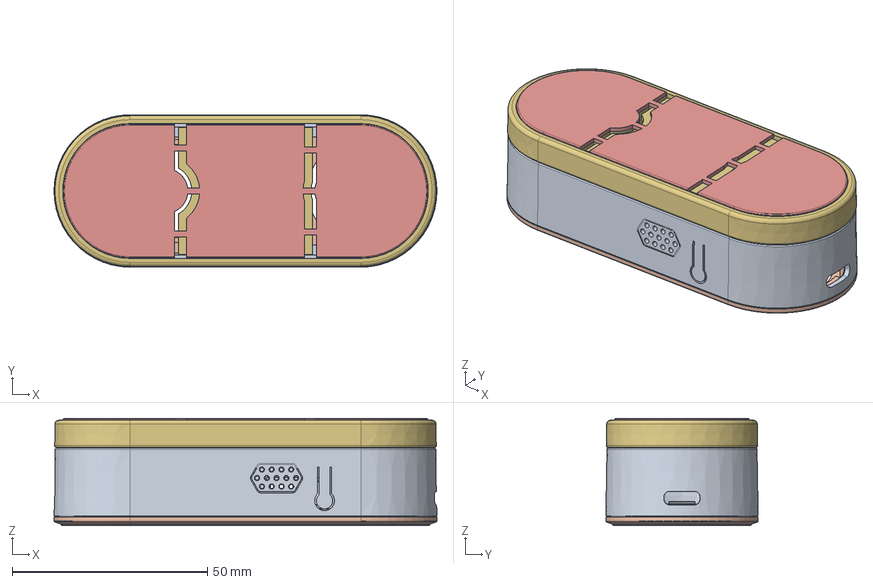
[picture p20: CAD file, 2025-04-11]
3D_files/T-Embed CC1101.stp
98.0 x 39.0 x 27.5 mm
066_T-EMBED_COV-A5_3_20
067_T-EMBED_COV-B5_5_1

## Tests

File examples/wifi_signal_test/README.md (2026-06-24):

# Wi-Fi Signal Diagnostic Example

[English](./README.md) | [简体中文](./README_CN.md)

This example is a Wi-Fi-only diagnostic sketch for the external-antenna T-Embed CC1101 Plus. BLE is intentionally disabled so the customer can focus on Wi-Fi signal testing without restart issues caused by Wi-Fi/BLE coexistence.

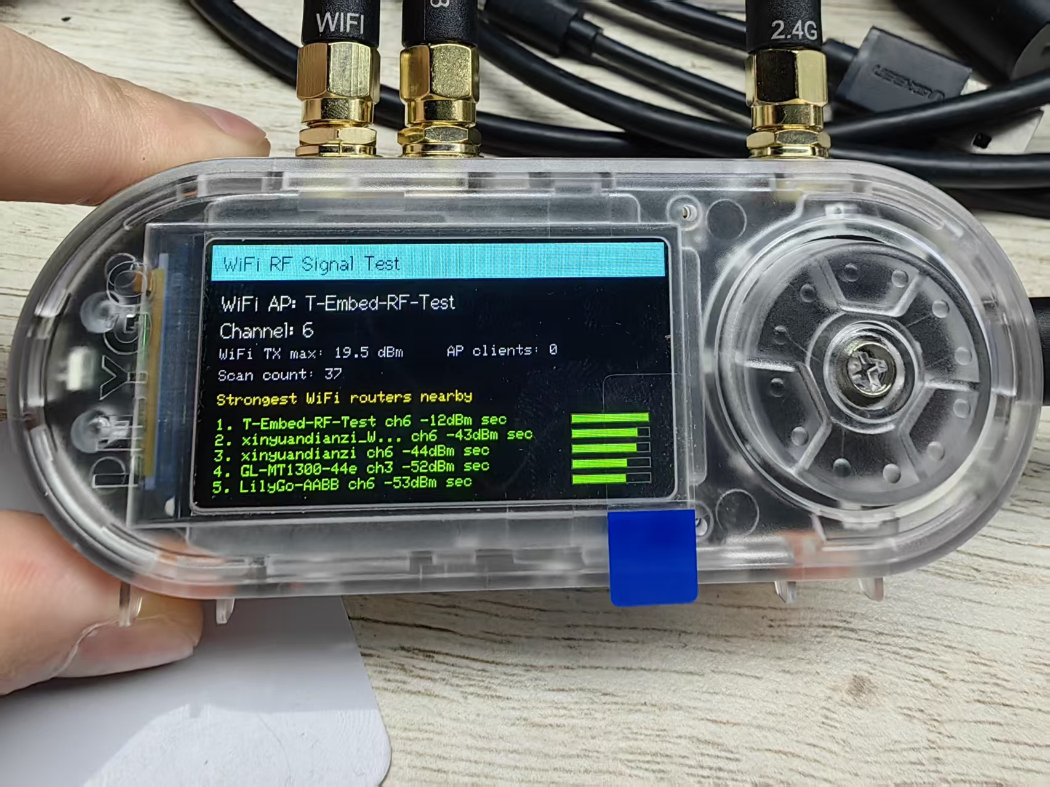
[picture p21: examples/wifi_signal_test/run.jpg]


## Features

- Starts a 2.4 GHz Wi-Fi AP named `T-Embed-RF-Test`, password `12345678`, so a phone can measure the signal transmitted by the device.
- Sets Wi-Fi max TX power to `19.5 dBm` and disables Wi-Fi sleep.
- Scans nearby routers every 10 seconds and prints RSSI in `dBm` on the screen and serial monitor.
- Shows the strongest nearby networks, AP client count, and current channel on the display.

## PlatformIO Steps

1. Install the external antenna before powering on the device.
2. Connect the device to the computer with USB.
3. Open `platformio.ini` in the repository root.
4. Make sure this line is enabled:

   ```ini
   src_dir = examples/wifi_ble_signal_test
   ```

5. Save `platformio.ini`.
6. Select the correct serial port in VSCode / PlatformIO.
7. Click the PlatformIO Upload button.
8. Open the serial monitor at `115200` baud.

## Customer Test Steps

1. Install a Wi-Fi analyzer app on a phone.
2. After flashing, the device screen should show `WiFi RF Signal Test`.
3. Use the phone Wi-Fi scanner to find `T-Embed-RF-Test`.
4. Record RSSI at `0.5 m`, `1.5 m`, and `3 m`.
5. Put the device near the router and record the router RSSI shown on the screen or serial monitor.
6. Send back screenshots and the serial log.

## RSSI Reference

- `-30 ~ -50 dBm`: very strong
- `-50 ~ -67 dBm`: normal
- `-67 ~ -75 dBm`: weak, but usually still usable
- `< -75 dBm`: poor signal

If Wi-Fi is still weak at close range with this sketch, check the external antenna, IPEX/U.FL connector, RF cable, antenna soldering, and assembly path first.

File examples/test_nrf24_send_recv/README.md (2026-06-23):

[English](./README.md) | [简体中文](./README_CN.md)

# nRF24 Send / Recv Test

`nrf24_send_recv_test` is an nRF24L01 send/receive test example for the `LilyGo T-Embed PN532`.

This example provides:

- An on-screen UI for channel, mode, last received text, and TX/RX counters
- Two working modes: `RX` and `TX BURST`
- Serial commands for channel, data rate, output power, ACK, and TX prefix
- WS2812 status indication
  - `RX` = green
  - `TX` = blue

## Hardware

The example uses the board definitions in `examples/utilities.h`.

### nRF24L01 pin mapping

| Signal | GPIO |
| --- | --- |
| `CS` | `44` |
| `CE` | `43` |
| `SCK` | `11` |
| `MOSI` | `9` |
| `MISO` | `10` |
| `IRQ` | not connected |

Notes:

- This example uses polling and does not require the nRF24 `IRQ` pin.
- The nRF24 module shares the SPI bus with the display. Bus switching is handled in the example.

## Default Settings

| Item | Value |
| --- | --- |
| Mode | `RX` |
| Channel | `76` |
| Frequency | `2476 MHz` |
| Data rate | `1000 kbps` |
| Output power | `0 dBm` |
| Auto ACK | `ON` |
| Address width | `5 bytes` |
| Pipe address | `01 23 45 67 89` |
| TX prefix | `T-Embed nRF24` |
| TX interval | `1000 ms` |

Frequency and channel relationship:

```text
Frequency(MHz) = 2400 + Channel
```

## Build And Flash

The project [platformio.ini](../../platformio.ini) is already configured to build this example:

```ini
src_dir = examples/nrf24_send_recv_test
```

Common commands:

```bash
pio run -e T_Embed_CC1101
pio run -e T_Embed_CC1101 -t upload
pio device monitor -b 115200
```

## On-Screen UI

The display shows:

- Current channel
- Current mode: `RX` or `TX BURST`
- Last received text
- RX length and RX count
- Current data rate / output power / ACK state

## Controls

### Buttons

- `USR`: cycle through preset channels `0 -> 40 -> 76 -> 125`
- `ENC`: switch `RX <-> TX BURST`

### Serial Commands

Serial baud rate: `115200`

Available commands:

```text
help
status
rx
tx
send <text>
ch <0-125>
rate 250|1000|2000
power -18|-12|-6|0
ack on|off
prefix <text>
```

Command summary:

- `help`: show help text
- `status`: print current radio settings
- `rx`: switch to receive mode
- `tx`: switch to periodic burst transmit mode
- `send <text>`: send one packet immediately
- `ch <0-125>`: set RF channel
- `rate 250|1000|2000`: set air data rate in `kbps`
- `power -18|-12|-6|0`: set TX output power
- `ack on|off`: enable or disable auto ACK
- `prefix <text>`: update the `TX BURST` text prefix

## ACK Notes

If the sender prints:

```text
[nRF24] TX failed: ACK not received.
```

usually the receiver did not return an auto-acknowledgement. Check:

- Both devices are on the same `channel`
- Both devices use the same `data rate`
- Both devices use the same `pipe address`
- The receiver is currently in `RX` mode
- Both sides use matching `Auto ACK` settings

If you only want to verify one-way reception first, set both devices to:

```text
ack off
```

## Typical Test Flow

1. Prepare two devices and flash this example to both of them.
2. Keep device A in `RX`.
3. Switch device B to `TX BURST`, or send `send hello` from the serial console.
4. Observe `Last RX` on device A and check the serial log.
5. To verify auto ACK, keep device A in `RX` and make sure both devices use `ack on`.

## File

Main sketch:

- [nrf24_send_recv_test.ino](./nrf24_send_recv_test.ino)

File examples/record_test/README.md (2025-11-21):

| Supported Targets | ESP32 | ESP32-S3 |
| --- | ----- | --- |

# I2S Digital Microphone Recording Example

(See the README.md file in the upper level 'examples' directory for more information about examples.)

In this example, we record a sample audio file captured from the digital MEMS microphone on the I2S peripheral using PDM data format.

The audio is recorded into the SDCard using WAVE file format.

| Audio Setting | Value |
|:---:|:---:|
| Sample Rate |44100 Hz|
| Bits per Sample |16 bits|

## How to Use Example

### Hardware Required

* A development board with ESP32 or ESP32S3 SoC (e.g., ESP32-DevKitC, ESP-WROVER-KIT, etc.)
* A USB cable for power supply and programming
* A digital microphone (SPK0838HT4H PDM output was used in this example)

The digital PDM microphone is connected on the I2S interface `I2S_NUM_0`.

The default GPIO configuration is the following:

|Mic | GPIO |
|:---:|:---:|
| PDM Clock | GPIO39 |
| PDM Data  | GPIO42 |

The SDCard is connected using SPI peripheral.

| SPI  | SDCard |  GPIO  |
|:----:|:---:|:---:|
| MISO | DAT0 | GPIO10 |
| MOSI | CMD | GPIO9  |
| SCLK | CLK | GPIO11 |
| CS | CD | GPIO13 |

## Example Output

Open the serial port and start recording for 15 seconds. You can use `i2s_set_clk` to change the Bits per Sample and the Sample Rate. The output log can be seen below:

```
ESP-ROM:esp32s3-20210327
Build:Mar 27 2021
rst:0x15 (USB_UART_CHIP_RESET),boot:0x8 (SPI_FAST_FLASH_BOOT)
Saved PC:0x4202ed26
SPIWP:0xee
mode:DIO, clock div:1
load:0x3fce3808,len:0x44c
load:0x403c9700,len:0xbd8
load:0x403cc700,len:0x2a80
entry 0x403c98d0
[   105][I][esp32-hal-psram.c:96] psramInit(): PSRAM enabled
SD Card Type: SDHC
SD Card Size: 30436MB
Starting recording for 15 seconds!
Opening File
Recording done!
File written on SDCard

```

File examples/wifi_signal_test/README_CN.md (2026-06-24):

# Wi-Fi 信号诊断示例

[English](./README.md) | [简体中文](./README_CN.md)

这个示例是给外置天线版 T-Embed CC1101 Plus 使用的 Wi-Fi 专用诊断程序。这里故意关闭了 BLE，只做 Wi-Fi 信号测试，同时避开 Wi-Fi / BLE 共存导致的重启问题。



## 功能

- 启动一个 2.4 GHz Wi-Fi AP，名称是 `T-Embed-RF-Test`，密码是 `12345678`，方便手机直接测设备发射出来的 Wi-Fi 信号。
- 将 Wi-Fi 最大发射功率设置为 `19.5 dBm`，并关闭 Wi-Fi 省电。
- 每 10 秒扫描一次周围路由器，并在屏幕和串口输出 `dBm` 单位的 RSSI。
- 屏幕上会显示附近最强的几个 Wi-Fi、当前信道和 AP 连接客户端数量。

## PlatformIO 使用步骤

1. 先装好外置天线，再给设备上电。
2. 用 USB 连接设备和电脑。
3. 打开仓库根目录下的 `platformio.ini`。
4. 确认下面这行是启用状态：

   ```ini
   src_dir = examples/wifi_ble_signal_test
   ```

5. 保存 `platformio.ini`。
6. 在 VSCode / PlatformIO 中选择正确的串口。
7. 点击 PlatformIO 的 Upload 按钮烧录。
8. 打开串口监视器，波特率设为 `115200`。

## 测试步骤

1. 在手机上安装一个 Wi-Fi 分析类 App。
2. 烧录后，设备屏幕应显示 `WiFi RF Signal Test`。
3. 用手机搜索 `T-Embed-RF-Test`。
4. 分别记录 `0.5 m`、`1.5 m`、`3 m` 距离下的 RSSI。
5. 把设备放到路由器旁边，记录屏幕或串口里显示的路由器 RSSI。
6. 把截图和串口日志发回。

## RSSI 参考

- `-30 ~ -50 dBm`：很强
- `-50 ~ -67 dBm`：正常
- `-67 ~ -75 dBm`：偏弱，但通常还能使用
- `< -75 dBm`：信号较差

如果用了这个示例后，设备在近距离下 Wi-Fi 依然明显偏弱，优先检查外置天线、IPEX / U.FL 座子、射频线、天线焊接和整机装配路径。

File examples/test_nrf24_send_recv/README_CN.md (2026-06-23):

[English](./README.md) | [简体中文](./README_CN.md)

# nRF24 收发测试

`nrf24_send_recv_test` 是为 `LilyGo T-Embed PN532` 适配的 nRF24L01 收发测试示例。

这个示例提供了：

- 屏幕 UI，显示当前信道、工作模式、最近一次接收文本和收发统计
- `RX` 与 `TX BURST` 两种工作模式
- 通过串口命令动态修改信道、速率、发射功率、ACK 和发送前缀
- WS2812 状态提示
  - `RX` = 绿色
  - `TX` = 蓝色

## 硬件说明

示例使用 `examples/utilities.h` 中的板级定义。

### nRF24L01 引脚定义

| 信号 | GPIO |
| --- | --- |
| `CS` | `44` |
| `CE` | `43` |
| `SCK` | `11` |
| `MOSI` | `9` |
| `MISO` | `10` |
| `IRQ` | 未连接 |

说明：

- 本示例使用轮询方式检查接收状态，不依赖 nRF24 的 `IRQ` 引脚。
- nRF24 与屏幕共用 SPI 总线，示例内部已经处理了总线切换。

## 默认参数

| 项目 | 默认值 |
| --- | --- |
| 模式 | `RX` |
| 信道 | `76` |
| 频率 | `2476 MHz` |
| 速率 | `1000 kbps` |
| 发射功率 | `0 dBm` |
| Auto ACK | `ON` |
| 地址宽度 | `5 bytes` |
| Pipe 地址 | `01 23 45 67 89` |
| 发送前缀 | `T-Embed nRF24` |
| 发送周期 | `1000 ms` |

频率与信道的关系：

```text
Frequency(MHz) = 2400 + Channel
```

## 编译与烧录

项目中的 [platformio.ini](../../platformio.ini) 已经指向本示例：

```ini
src_dir = examples/nrf24_send_recv_test
```

常用命令：

```bash
pio run -e T_Embed_CC1101
pio run -e T_Embed_CC1101 -t upload
pio device monitor -b 115200
```

## 屏幕显示

屏幕上会显示：

- 当前信道
- 当前模式：`RX` 或 `TX BURST`
- 最近一次收到的文本
- 接收长度和接收计数
- 当前速率 / 发射功率 / ACK 状态

## 操作方式

### 按键

- `USR`：循环切换预设信道 `0 -> 40 -> 76 -> 125`
- `ENC`：切换 `RX <-> TX BURST`

### 串口命令

串口波特率：`115200`

支持的命令：

```text
help
status
rx
tx
send <text>
ch <0-125>
rate 250|1000|2000
power -18|-12|-6|0
ack on|off
prefix <text>
```

命令说明：

- `help`：打印帮助信息
- `status`：打印当前无线参数
- `rx`：切换到接收模式
- `tx`：切换到周期发送模式
- `send <text>`：立即发送一包文本
- `ch <0-125>`：设置 RF 信道
- `rate 250|1000|2000`：设置空口速率，单位 `kbps`
- `power -18|-12|-6|0`：设置发射功率
- `ack on|off`：打开或关闭自动应答
- `prefix <text>`：修改 `TX BURST` 的发送前缀

## ACK 说明

如果发送端日志出现：

```text
[nRF24] TX failed: ACK not received.
```

通常表示接收端没有返回自动应答。请重点检查：

- 两端是否在同一个 `channel`
- 两端是否使用相同的 `data rate`
- 两端是否使用相同的 `pipe address`
- 接收端当前是否处于 `RX` 模式
- 两端的 `Auto ACK` 设置是否一致

如果只是先验证单向接收，可以先把两端都设置成：

```text
ack off
```

## 典型测试流程

1. 准备两块设备，并都烧录本示例。
2. 让 A 设备保持在 `RX` 模式。
3. 让 B 设备切换到 `TX BURST`，或者在串口发送 `send hello`。
4. 观察 A 设备屏幕上的 `Last RX` 和串口日志。
5. 如果要验证 ACK，请保持 A 在 `RX` 模式，并确保两端都使用 `ack on`。

## 文件

主程序文件：

- [nrf24_send_recv_test.ino](./nrf24_send_recv_test.ino)

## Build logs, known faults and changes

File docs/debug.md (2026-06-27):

# 为什么电池电量耗尽，插入USB 会一直进入下载模式？
~~~
原因分析：这是电池低压 + USB 插入时的电源切换 + 自动下载电路共同导致的典型问题。核心原因自动下载电路（Auto Boot/Reset Circuit）
大多数 ESP32-S3 开发板（尤其是带 USB-UART 芯片如 CP2102、CH9102 的）都有 DTR/RTS 自动控制 GPIO0（BOOT）和 EN（RESET）的电路。
当你插入 USB 时，USB-UART 芯片上电，会产生一个复位脉冲 + GPIO0 拉低的动作，让芯片自动进入 Download Mode（boot:0x0）。
这本来是方便烧录设计的，但低电压下表现异常。

电池电压只有 3.45V（偏低）  LiPo 电池标称 3.7V，3.45V 已接近欠压保护边缘（很多保护板在 3.2~3.4V 就会切断）。  
ESP32-S3 正常工作电压 3.0~3.6V，3.45V 勉强够用，但负载能力变差，电压容易跌落。  
插入 USB（5V）瞬间，板子上电源切换电路（二极管或 PMOS）会从电池切换到 USB 供电。这个切换过程会产生瞬间电压波动/毛刺，导致 EN 或 GPIO0 信号不干净，芯片复位后直接卡在 Download Mode。

为什么按复位键才能退出？
进入 Download Mode 后，芯片就停在等待烧录状态。只有硬件复位（EN 拉低） 并且 GPIO0 不是低电平 时，才会正常启动用户程序。
低压 + 电源切换导致的复位信号不彻底，所以一直卡住，直到你手动按复位键（强行干净复位）。

验证与解决办法立即解决（临时）：插入 USB 前先按住 BOOT 键（GPIO0），再插 USB，然后松开 → 看是否稳定。
或者插 USB 后直接按一下复位键，观察是否正常启动。
电池充满电（>3.8V）再测试，问题大概率消失。

长期解决：给电池充电 或换一块容量/电压更高的电池。
在电源切换电路加电容（很多玩家在 3.3V 或 EN 脚加 10~47uF 电容，改善切换时的毛刺）。
修改固件：在 setup() 最前面加延迟或检测 USB 插入（用 USB.vbusPresent()），避免低压下异常行为。
硬件优化（推荐）：用带更好电源管理的板子（如某些 XIAO ESP32-S3 或 Adafruit Feather S3，有更完善的 USB/Battery 切换）。
或者在电池和板子间加低压保护/升压模块（确保始终稳定 3.3V）。

如果你经常这样操作，烧录前手动进入下载模式（按住 BOOT + 按复位），烧完后再按复位退出。

把你的具体开发板型号（比如 LilyGo、XIAO、自定义板等）告诉我，我可以给你更针对性的电路或代码建议。
另外，电池长期在 3.45V 以下运行不推荐，容易损伤电池和芯片稳定性。充满电再用会好很多！

也就是电池在低压没电的时候，插入USB可能会存在触发芯片进入下载模式。现象就是你怎么插USB跟按按键都没用。只有充电到3.5V以上然后按复位键的时候才会重新开机。
~~~

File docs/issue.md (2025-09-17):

The issue of no display on the screen: 

屏幕没有显示的问题：

1. Rule out the possibility of no program installed; download the factory firmware to reset and see if it works normally.
 排除没有程序的问题；下载出厂固件复位，看能否正常工作；

2. If the screen still doesn't display after installing the program, remove the battery and only use USB power supply. Then unplug and plug in the USB to power on again. 如果有程序屏幕还是没有显示，就把电池拔掉，只使用USB供电，在插拔usb重新上电；

3. If the screen still doesn't display after completing the above two steps, it might be that the screen cable is loose. You can disassemble the device and reinsert the screen cable.如果做完上面两部屏幕还是不显示，可能是屏幕排线松了，可以把设备拆了，然后重新插一下屏幕排线；

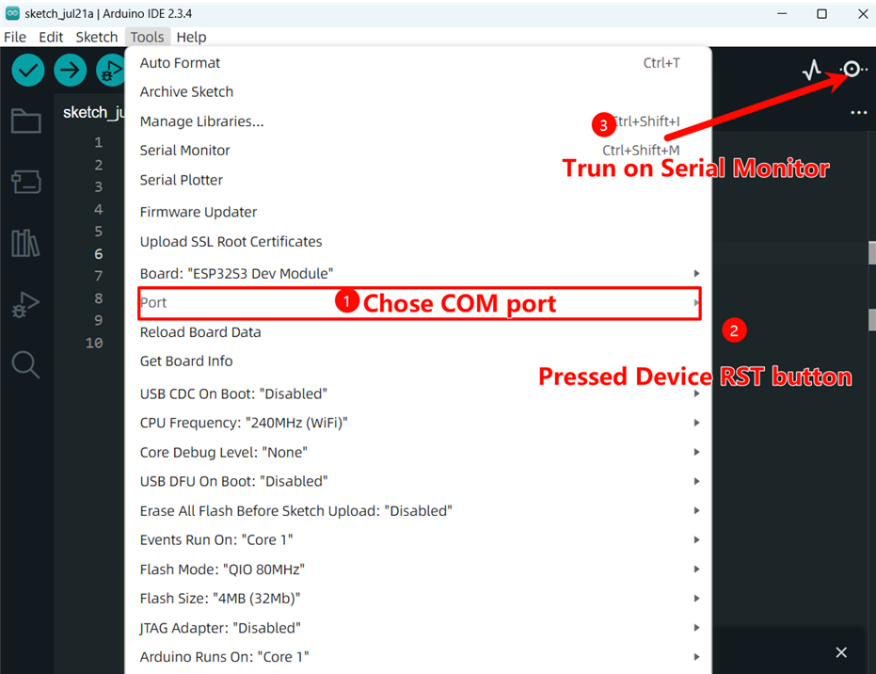
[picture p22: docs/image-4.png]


What about the information after opening SerialMonitor? It's not the log for uploading the firmware. 
打开SerialMontor 之后的信息呢 ？不是要上传固件的日志

Open the back cover, press the button close to the ESP to reset. If it still doesn't work, try removing the battery and reinserting it.
打开背盖，按下靠近esp 的 按键进行复位，如果还是不行，试试拔掉电池，重新插上试试，

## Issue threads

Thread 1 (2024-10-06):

Can the two qwiic connectors be used as input sensors?

jiangxw, 2024-10-06:
So I can program an action based on these inputs without worrying about I2C protocol? If not, anyway that I can get simple GPIO inputs from T-Embed-CC1101?

ShallowGreen123, 2024-10-16:
T-Embed-CC1101 supports I2C input and can also obtain GPIO status

Closed 2024-11-30.

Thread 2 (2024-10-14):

De-brick instructions

tsbo, 2024-10-14:
I just bought my T-Embed CC1101 and managed to brick it using Arduino (maybe i did not provide any of the values from the screenshot, even though i checked them twice).
The device now is not lighting up and not showing any liveness at all, but erase flash and uploading are completed successful - without any visible changes.
Please provide details how to put it back to "normal"

ShallowGreen123, 2024-10-16:
你可以告诉我这些信息吗，为了帮助你解决问题。
1. 使用的什么环境编译的代码，是 PIO还是 Arduno？
2. 如果使用的是 Arduino，用的什么版本？
3. 是编译下载哪一个例程？

ShallowGreen123, 2024-10-16:
Can you tell me this information to help you solve the problem?
1. What environment did you use to compile the code, PIO or Arduno?
2. If you used Arduino, what version did you use?
3. Which example did you compile and download?

tsbo, 2024-10-17:
Hello, thank you for getting back to me!
I tried Arduino 1.8 and 2.2 for majority of the examples here (lvgl, display, cc1101). They are compiling, uploading - but then nothing is shown on the screen and device seems not working. I tried examples from T-Embed project - that are also compiling ,but not showing anything on the screen.
Following the instructions on sections Tips from https://github.com/Xinyuan-LilyGO/T-Embed , i managed to de-brick it. Trying with the ESP32 stock examples in Arduino, flashing is working, but reseting after flashing is not working - i need to unplug and plug back the usb cable, in order to restart the device.
I needed to remove also the battery, in order to be able to restart the device using the usb cable

ShallowGreen123, 2024-10-17:
T-Embed-CC1101 and T-Embed are not compatible.

You can confirm whether your board is T-Embed-CC1101 or T-Embed.

Then, go to the corresponding Github repository and run the examples in it;

T-Embed-CC1101: https://github.com/Xinyuan-LilyGO/T-Embed-CC1101

T-Embed: https://github.com/Xinyuan-LilyGO/T-Embed

tsbo, 2024-10-17:
mine device is T-Embed CC1101 - the fresh version with 1300 mA battery

Closed 2024-11-06.

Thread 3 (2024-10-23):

LORA init failed

jiangxw, 2024-10-23:
If I go to Settings->About System, both "LORA init" and "TF Card" show "FAIL" on a brand new device. how do I fix that?

ShallowGreen123, 2024-10-23:
You can use `examples/CC1101_xxx` and `examples/tf_card_test` to test whether Lora and TF card are normal respectively;

jiangxw, 2024-10-23:
I flashed cc1101_send_irq to the device. But "LORA init" still shows up as "FAIL". In addition, the interface did not change. What did I miss?

The following is the log for flashing the firmware
------------------------------------------------------------------------------------
Retrieving maximum program size .pio/build/cc1101_send_irq/firmware.elf
Checking size .pio/build/cc1101_send_irq/firmware.elf
Advanced Memory Usage is available via "PlatformIO Home > Project Inspect"
RAM:   [==        ]  19.1% (used 62584 bytes from 327680 bytes)
Flash: [==        ]  24.4% (used 1600073 bytes from 6553600 bytes)
Configuring upload protocol...
AVAILABLE: cmsis-dap, esp-bridge, esp-builtin, esp-prog, espota, esptool, iot-bus-jtag, jlink, minimodule, olimex-arm-usb-ocd, olimex-arm-usb-ocd-h, olimex-arm-usb-tiny-h, olimex-jtag-tiny, tumpa
CURRENT: upload_protocol = esptool
Looking for upload port...
Auto-detected: /dev/cu.usbmodem2101
Uploading .pio/build/cc1101_send_irq/firmware.bin
esptool.py v4.5.1
Serial port /dev/cu.usbmodem2101
Connecting...
Chip is ESP32-S3 (revision v0.2)
Features: WiFi, BLE
Crystal is 40MHz
MAC: 48:ca:43:36:f0:10
Uploading stub...
Running stub...
Stub running...
Configuring flash size...
Flash will be erased from 0x00000000 to 0x00003fff...
Flash will be erased from 0x00008000 to 0x00008fff...
Flash will be erased from 0x0000e000 to 0x0000ffff...
Flash will be erased from 0x00010000 to 0x00196fff...
Compressed 15104 bytes to 10401...
Writing at 0x00000000... (100 %)
Wrote 15104 bytes (10401 compressed) at 0x00000000 in 0.2 seconds (effective 492.5 kbit/s)...
Hash of data verified.
Compressed 3072 bytes to 146...
Writing at 0x00008000... (100 %)
Wrote 3072 bytes (146 compressed) at 0x00008000 in 0.0 seconds (effective 542.4 kbit/s)...
Hash of data verified.
Compressed 8192 bytes to 47...
Writing at 0x0000e000... (100 %)
Wrote 8192 bytes (47 compressed) at 0x0000e000 in 0.1 seconds (effective 711.1 kbit/s)...
Hash of data verified.
Compressed 1600496 bytes to 1033142...
Writing at 0x00010000... (1 %)
Writing at 0x000171cc... (3 %)
Writing at 0x000251b3... (4 %)
Writing at 0x0002c8f7... (6 %)
Writing at 0x00031e47... (7 %)
Writing at 0x00037a9c... (9 %)
Writing at 0x00042e30... (10 %)
Writing at 0x0004e37d... (12 %)
Writing at 0x00059130... (14 %)
Writing at 0x0006d867... (15 %)
Writing at 0x00074ddf... (17 %)
Writing at 0x0007a3ca... (18 %)
Writing at 0x0007faaf... (20 %)
Writing at 0x000848ca... (21 %)
Writing at 0x00089c56... (23 %)
Writing at 0x0008ed1d... (25 %)
Writing at 0x00094610... (26 %)
Writing at 0x00099548... (28 %)
Writing at 0x0009e685... (29 %)
Writing at 0x000a389b... (31 %)
Writing at 0x000a9242... (32 %)
Writing at 0x000ae721... (34 %)
Writing at 0x000b3b8a... (35 %)
Writing at 0x000b878d... (37 %)
Writing at 0x000bd63c... (39 %)
Writing at 0x000c310f... (40 %)
Writing at 0x000c90d0... (42 %)
Writing at 0x000ced05... (43 %)
Writing at 0x000d4a2f... (45 %)
Writing at 0x000da786... (46 %)
Writing at 0x000dfd1b... (48 %)
Writing at 0x000e5973... (50 %)
Writing at 0x000eaaf3... (51 %)
Writing at 0x000efdf8... (53 %)
Writing at 0x000f4dac... (54 %)
Writing at 0x000f9cbd... (56 %)
Writing at 0x000fec62... (57 %)
Writing at 0x00103b27... (59 %)
Writing at 0x00108d31... (60 %)
Writing at 0x0010debf... (62 %)
Writing at 0x00112ef9... (64 %)
Writing at 0x00117d20... (65 %)
Writing at 0x0011cc3a... (67 %)
Writing at 0x0012265d... (68 %)
Writing at 0x001279d0... (70 %)
Writing at 0x0012cd8d... (71 %)
Writing at 0x00131b60... (73 %)
Writing at 0x00136adf... (75 %)
Writing at 0x0013bbef... (76 %)
Writing at 0x0014108b... (78 %)
Writing at 0x0014638c... (79 %)
Writing at 0x0014babe... (81 %)
Writing at 0x00151346... (82 %)
Writing at 0x00156a4c... (84 %)
Writing at 0x0015bf9f... (85 %)
Writing at 0x00161918... (87 %)
Writing at 0x001678fd... (89 %)
Writing at 0x00170219... (90 %)
Writing at 0x00177b3f... (92 %)
Writing at 0x0017d6ad... (93 %)
Writing at 0x0018569e... (95 %)
Writing at 0x0018affe... (96 %)
Writing at 0x0019058f... (98 %)
Writing at 0x00196629... (100 %)
Wrote 1600496 bytes (1033142 compressed) at 0x00010000 in 11.7 seconds (effective 1097.3 kbit/s)...
Hash of data verified.

Leaving...
Hard resetting via RTS pin...
=========================================== [SUCCESS] Took 24.01 seconds ===========================================

Environment      Status    Duration
---------------  --------  ------------
cc1101_send_irq  SUCCESS   00:00:24.013
============================================ 1 succeeded in 00:00:24.013 ============================================
 *  Terminal will be reused by tasks, press any key to close it.

ShallowGreen123, 2024-10-24:
Can I see the log output of the cc1101_send_irq log?

jiangxw, 2024-10-24:
The following is the output. Does it require a SD card to function? I used platformio to upload the firmware and it succeeded as in above log. But I'm not sure if the firmware actually take effect because nothing in the UI changed.

***************************************
[  1980][I][XPowersCommon.tpp:421] begin(): SDA:8 SCL:18
[  1980][W][Wire.cpp:301] begin(): Bus already started in Master Mode.
getInputCurrentLimit: 3250 mA
getChargerConstantCurr: 832 mA
[CC1101] Initializing ... 315.00 MHz
failed, code -16
[  2154][W][Wire.cpp:301] begin(): Bus already started in Master Mode.
Found chip PN532
Firmware ver. 1.6
Waiting for an ISO14443A Card ...
EMBED_COLOR_BG:0x161823
EMBED_COLOR_FOCUS_ON:0xb4dc38
EMBED_COLOR_TEXT:0xffffff
EMBED_COLOR_BORDER:0xbbbbbb
EMBED_COLOR_PROMPT_BG:0xfffee6
EMBED_COLOR_PROMPT_TXT:0x1e1e00
[  2758][W][sd_diskio.cpp:174] sdCommand(): no token received
[  2858][W][sd_diskio.cpp:174] sdCommand(): no token received
[  2958][W][sd_diskio.cpp:174] sdCommand(): no token received
[  3057][E][sd_diskio.cpp:199] sdCommand(): Card Failed! cmd: 0x00
[  3058][W][sd_diskio.cpp:516] ff_sd_initialize(): GO_IDLE_STATE failed
[  3059][E][sd_diskio.cpp:805] sdcard_mount(): f_mount failed: (3) The physical drive cannot work
[  3068][W][sd_diskio.cpp:174] sdCommand(): no token received
[  3173][W][sd_diskio.cpp:174] sdCommand(): no token received
[  3273][W][sd_diskio.cpp:174] sdCommand(): no token received
[  3372][E][sd_diskio.cpp:199] sdCommand(): Card Failed! cmd: 0x00
Card Mount Failed
[  3373][E][vfs_api.cpp:24] open(): File system is not mounted
Failed to open directory

ShallowGreen123, 2024-10-24:
You can try using the `factory_test` example. My tests are OK.

The `factory` example does have the problem you described, thanks for the feedback;

jiangxw, 2024-10-24:
I actually suspect that it's still running the default firmware rather than the firmware that I flashed. Anything other than flashing the firmware that I need to do?

jiangxw, 2024-10-24:
factory_test works sometimes, but it sometimes also fails to init cc1101 with error code -16.

I tried both cc1101_send_irq and cc1101_recv_irq, they both crash on boot. How do I fix this? Is there a good commit that I can try?

Here is the log for cc1101_send_irq:

ELF file SHA256: d5245029f2b9ee48

Rebooting...
ESP-ROM:esp32s3-20210327
Build:Mar 27 2021
rst:0xc (RTC_SW_CPU_RST),boot:0x8 (SPI_FAST_FLASH_BOOT)
Saved PC:0x40376fd0
SPIWP:0xee
mode:DIO, clock div:1
load:0x3fce3808,len:0x44c
load:0x403c9700,len:0xbd8
load:0x403cc700,len:0x2a80
entry 0x403c98d0
[    96][I][esp32-hal-psram.c:96] psramInit(): PSRAM enabled
[CC1101] Initializing ... 315.00 MHz
failed, code -16

ShallowGreen123, 2024-10-24:
Consider replacing a CC1101 for you, it seems that there is a problem with Lora's SPI connection。

jiangxw, 2024-10-25:
What's the process to get it replaced?

jiangxw, 2024-10-27:
I turned on SPI debug and here is more log

ESP-ROM:esp32s3-20210327
Build:Mar 27 2021
rst:0xc (RTC_SW_CPU_RST),boot:0x8 (SPI_FAST_FLASH_BOOT)
Saved PC:0x40376fd0
SPIWP:0xee
mode:DIO, clock div:1
load:0x3fce3808,len:0x44c
load:0x403c9700,len:0xbd8
load:0x403cc700,len:0x2a80
entry 0x403c98d0
[    96][I][esp32-hal-psram.c:96] psramInit(): PSRAM enabled
[CC1101] Initializing ... 315.00 MHz
RLB_SPI: R      71      14
RLB_SPI: CMD    W       30      00
RLB_SPI: CMD    W       36      0F
RLB_SPI: R      75      0
RLB_SPI: R      75      1
RLB_SPI: R      18      F
RLB_SPI: W      18      1F
RLB_SPI: R      18      4
RLB_SPI: R      18      F
RLB_SPI: R      18      FF
RLB_SPI: R      18      4
RLB_SPI: R      18      F
RLB_SPI: R      18      FF
RLB_SPI: R      18      4
RLB_SPI: R      18      F
RLB_SPI: R      18      FF
RLB_SPI: R      18      4
RLB_SPI: R      18      F
RLB_SPI: R      18      FF
RLB_SPI: R      18      4
RLB_SPI: R      18      F
RLB_SPI: R      18      FF
RLB_SPI: R      18      4
RLB_SPI: R      18      F
RLB_SPI: R      18      FF
RLB_SPI: R      18      4
RLB_SPI:
RLB_SPI: address:       0x18
RLB_SPI: bits:          5 4
RLB_SPI: value:         0x10
RLB_SPI: current:       0xF
RLB_SPI: mask:          0x30
RLB_SPI: new:           0x1F
RLB_SPI: read:          0x4
RLB_SPI: R      18      F
RLB_SPI: W      18      D
RLB_SPI: R      18      4
RLB_SPI: R      18      F
RLB_SPI: R      18      FF
RLB_SPI: R      18      4
RLB_SPI: R      18      F
RLB_SPI: R      18      FF
RLB_SPI: R      18      4
RLB_SPI: R      18      F
RLB_SPI: R      18      FF
RLB_SPI: R      18      4
RLB_SPI: R      18      F
RLB_SPI: R      18      FF
RLB_SPI: R      18      4
RLB_SPI: R      18      F
RLB_SPI: R      18      FF
RLB_SPI: R      18      4
RLB_SPI: R      18      F
RLB_SPI: R      18      FF
RLB_SPI: R      18      4
RLB_SPI:
RLB_SPI: address:       0x18
RLB_SPI: bits:          1 1
RLB_SPI: value:         0x0
RLB_SPI: current:       0xF
RLB_SPI: mask:          0x2
RLB_SPI: new:           0xD
RLB_SPI: read:          0x4
failed, code -16
E (10447) task_wdt: Task watchdog got triggered. The following tasks did not reset the watchdog in time:
E (10447) task_wdt:  - IDLE (CPU 0)
E (10447) task_wdt: Tasks currently running:
E (10447) task_wdt: CPU 0: loopTask
E (10447) task_wdt: CPU 1: IDLE
E (10447) task_wdt: Aborting.

abort() was called at PC 0x4200b34c on core 0

Backtrace: 0x403773c2:0x3fc936a0 0x4037ab81:0x3fc936c0 0x403804f9:0x3fc936e0 0x4200b34c:0x3fc93760 0x40378529:0x3fc93780 0x42001add:0x3fcebeb0 0x4200593a:0x3fcebee0

  #0  0x403773c2:0x3fc936a0 in panic_abort at /Users/ficeto/Desktop/ESP32/ESP32S2/esp-idf-public/components/esp_system/panic.c:408
  #1  0x4037ab81:0x3fc936c0 in esp_system_abort at /Users/ficeto/Desktop/ESP32/ESP32S2/esp-idf-public/components/esp_system/esp_system.c:137
  #2  0x403804f9:0x3fc936e0 in abort at /Users/ficeto/Desktop/ESP32/ESP32S2/esp-idf-public/components/newlib/abort.c:46
  #3  0x4200b34c:0x3fc93760 in task_wdt_isr at /Users/ficeto/Desktop/ESP32/ESP32S2/esp-idf-public/components/esp_system/task_wdt.c:176 (discriminator 3)
  #4  0x40378529:0x3fc93780 in _xt_lowint1 at /Users/ficeto/Desktop/ESP32/ESP32S2/esp-idf-public/components/freertos/port/xtensa/xtensa_vectors.S:1114
  #5  0x42001add:0x3fcebeb0 in setup() at examples/cc1101_send_irq/cc1101_send_irq.ino:79
  #6  0x4200593a:0x3fcebee0 in loopTask(void*) at /Users/xiaowei/.platformio/packages/framework-arduinoespressif32/cores/esp32/main.cpp:42

ELF file SHA256: 2653754c38836ee4

Closed 2024-12-16.

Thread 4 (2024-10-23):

Can't provision WiFi using EspTouch

jiangxw, 2024-10-23:
I tried to configure WiFi and got a timeout. The "help" tells me to configure using EspTouch. So I followed, but the device doesn't show up in either EspTouch or EspTouch V2. How can I configure WiFi?

ShallowGreen123, 2024-10-23:
1. To download the EspTouch software, you can scan the QR code below to download;
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

2. Enter EspTouch on your phone. Please note that your phone must be connected to WIIF first (not 5G), then click EspTouch.
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

3. Enter the WIFI password on your phone; the device should be in the WIFI interface;
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

4. Click Confirm on your phone; click Config on your device; then wait for the network configuration to succeed;
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

5. The following is a successful network configuration
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

jiangxw, 2024-10-23:
That worked. thanks!

tally0highwayman, 2025-01-28:
I followed these exact steps and they did not work on my new, out-of-the-box T-Embed C1101.
SF Version: v1.1-20250109
HD Version: v1.0-20240729

Closed 2024-12-07.

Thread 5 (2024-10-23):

How do I turn on the device after I shut it down

jiangxw, 2024-10-23:
I went to Settings -> Shutdown. But I can't find a way to turn it on by pushing the buttons. The only way I found is to connect to a computer using USB. How do I do that?

ShallowGreen123, 2024-10-23:
When the device is turned off, you can turn it on by inserting a USB. Of course, you can also `long press` the power button on the back of the device.

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

jiangxw, 2024-10-23:
The long press did not work for me on my CC1101

Huzzla101, 2025-01-23:
Also u have the deep sleep function that is almost like turn it off. if u use that then u can just click the top botton once to start it up

Closed 2024-12-08.

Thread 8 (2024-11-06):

Help un-brick T-Embed-CC1101

xathugameboy, 2024-11-06:
I tried installing 3rd firmware but it did not work. Installed factory firmware via flash_download_tool_3.9.7. My PC still detects the device (COMxx) when connected but the device does not turn on.
Please help me find out where to find firmware for the T-embed and how to take it back to "normal",

ShallowGreen123, 2024-11-06:
If you plug in T-Embed-CC1101, the serial port can be detected, but it cannot be opened. This may be occupied by some applications. If you cannot find the occupied program, you can directly restart the computer.

You can burn `firmware/firmware_factory_test_20241014.bin` to restore it.

xathugameboy, 2024-11-06:
> If you plug in T-Embed-CC1101, the serial port can be detected, but it cannot be opened. This may be occupied by some applications. If you cannot find the occupied program, you can directly restart the computer.
>
> You can burn `firmware/firmware_factory_test_20241014.bin` to restore it.

Thanks for very quick replies. I burned firmware/firmware_factory_test_20241014.bin via flash_download_tool_3.9.7 successfully as the instructions in the files but the T-Embed still does not turn on. Could you provide a link or video installing it or webpages?

ShallowGreen123, 2024-11-06:
Use flash_download_tool_3.9.7 to download the program, you need to press the reset key;

Open the back cover of the device and press the reset button in the following position, which may be difficult to press, you can take a thin object and poke it;

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

xathugameboy, 2024-11-06:
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

Many thanks! It worked. <3

Closed 2024-11-06.

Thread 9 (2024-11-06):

Battery charge

bmorcelli, 2024-11-06:
Hello,

I can´t get the battery to charge when connected to USB, unless I get back to Factory app

I'm using this code:
lib: lewisxhe/XPowersLib @ ^0.2.6

```
#include <XPowersLib.h>
extern XPowersPPM PPM;

void setup() {
// code code

Wire.begin(8, 18);
      pmu_ret = PPM.init(Wire, 8, 18, BQ25896_SLAVE_ADDRESS);
      if(pmu_ret) {
          PPM.setSysPowerDownVoltage(3300);
          PPM.setInputCurrentLimit(3250);
          Serial.printf("getInputCurrentLimit: %d mA\n",PPM.getInputCurrentLimit());
          PPM.disableCurrentLimitPin();
          PPM.setChargeTargetVoltage(4208);
          PPM.setPrechargeCurr(64);
          PPM.setChargerConstantCurr(832);
          PPM.getChargerConstantCurr();
          Serial.printf("getChargerConstantCurr: %d mA\n",PPM.getChargerConstantCurr());
          PPM.enableADCMeasure();
          PPM.enableCharge();
      }
// code code
}

```

ShallowGreen123, 2024-11-07:
Try `examples/bq25896_test`

The example uses the library lewisxhe/ XPowersLib@ \^0.2.4

After downloading this program, open the serial port;

bmorcelli, 2024-11-07:
I changed the library and tested with the example setup, didn´t work either..

it only worked afer add:
´´´
     PPM.enableOTG();
     PPM.disableOTG();
´´´

the working code was:

```
    bool pmu_ret = false;
    Wire.begin(8, 18);
    pmu_ret = PPM.init(Wire, 8, 18, BQ25896_SLAVE_ADDRESS);
    if(pmu_ret) {
        PPM.setSysPowerDownVoltage(3300);
        PPM.setInputCurrentLimit(3250);
        Serial.printf("getInputCurrentLimit: %d mA\n",PPM.getInputCurrentLimit());
        PPM.disableCurrentLimitPin();
        PPM.setChargeTargetVoltage(4208);
        PPM.setPrechargeCurr(64);
        PPM.setChargerConstantCurr(832);
        PPM.getChargerConstantCurr();
        Serial.printf("getChargerConstantCurr: %d mA\n",PPM.getChargerConstantCurr());
        PPM.enableADCMeasure();
        PPM.enableCharge();
    }
     PPM.enableOTG();
     PPM.disableOTG();
```

thank you for your help.

Closed 2024-11-07.

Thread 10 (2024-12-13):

Download Mode

rouing, 2024-12-13:
I am holding down the boot button while inserting the USB but it refuses to go into download mode. What am I missing?

rouing, 2024-12-14:
Ok, so it looks like I have to hold down the boot button and the encoder button at the same time.

rouing, 2024-12-15:
Look at me, I'm an idiot. The center button on the encoder IS the BOOT button, I was assuming the button on the side of the device was.

Lovely.

Closed 2024-12-15.

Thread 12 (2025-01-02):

About tech specs

Buh7buv6, 2025-01-02:
The pn532 module shows only support for 13.56mhz nfc in specs, but the site shows support for both 125khz and 13.56 mhz.

Could you please specify if there is also a RFID module present for 125khz?

, and also please put more detailed tech specs on site as also the battery is somewhere mentioned as 1500mah.

Buh7buv6, 2025-02-03:
What about 125khz activity ? It says in product site that there is support for 125khz but in here nothing is mentioned.

Huzzla101, 2025-03-05:
Tech Spec is marvellous.-.   --

On Wed, Mar 5, 2025 at 3:43 AM github-actions[bot] ***@***.***>
wrote:

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

--
Kind Regards

Christian R.

May Prosperity allways be with us!!

Closed 2025-04-20.

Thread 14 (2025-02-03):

125khz

Buh7buv6, 2025-02-03:
What about 125khz activity ? It says in product site that there is support for 125khz but in here nothing is mentioned.

ShallowGreen123, 2025-02-06:
The PN532 supports operating at 13.56 MHz. The official description of the PN532 is incorrect.

GingerTheKidd2, 2025-02-12:
does this mean 125khz isnt supported on the device?

Huzzla101, 2025-02-13:
Also its important to know that the pin out above SD card is QWIIC 1.0 mm
and not 1,25 mm ... =)  I love this toy its beautiful.. We need celebrate
every day !!

On Wed, Feb 12, 2025 at 4:58 PM GingerTheKidd2 ***@***.***>
wrote:

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

--
Kind Regards

Christian R.

May Prosperity allways be with us!!

Closed 2025-03-30.

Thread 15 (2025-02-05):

power drain

GuMAZ777, 2025-02-05:
how do you full turn off embed cc1101. i tried pressing the button on the inside to no avail. even holding it down for 18sec. all it did then was shut down and start back up. i’m running the bruce firmware.  couldn’t they add full shut down to config?. because all that does is put it into a deep sleep mode. thanks

ShallowGreen123, 2025-02-06:
The PN532 supports operating at 13.56 MHz. The official description of the PN532 is incorrect.

ShallowGreen123, 2025-02-06:
To fully disable T-Embed-CC1101, you need to disable the BQ25896 power chip;

Long press the PWR button in T-Embed-CC1101 to start the BQ25896 chip power supply;

Refer to closing BQ25896 [examples/bq25896_shutdown](https://github.com/Xinyuan-LilyGO/T-Embed-CC1101/tree/master/examples/bq25896_shutdown)

GuMAZ777, 2025-02-06:
tried it with the battery connected. still nothing. is there a video on it?

ShallowGreen123, 2025-02-06:
I just modified the program to facilitate testing;

1. First download the program [examples/bq25896_shutdown](https://github.com/Xinyuan-LilyGO/T-Embed-CC1101/tree/master/examples/bq25896_shutdown); The function of this program is to shut down after 5S.

2. Then, when using battery power, without inserting USB, measure the voltage according to the following figure.
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

3. Then long press the PWR key to power on (there will be voltage on the ammeter), and automatically shut down after 5 seconds (the ammeter voltage is 0); After shutdown, press PWR to start up and reciprocate this process;

The above tests the T-Embed-CC1101 procedure;

Closed 2025-03-23.

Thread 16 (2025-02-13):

Device came broken

Uld0fw1n, 2025-02-13:
Device came with a broken screen and the power button doesnt work. Can you send a new device?

ShallowGreen123, 2025-02-14:
Of course. Where did you buy it? Contact customer service to exchange it for you.

Uld0fw1n, 2025-02-14:
> Of course. Where did you buy it? Contact customer service to exchange it for you.

Bought is from official lilygo site

Uld0fw1n, 2025-02-14:
> Of course. Where did you buy it? Contact customer service to exchange it for you.

Power button works. The screen is cracked

Closed 2025-03-31.

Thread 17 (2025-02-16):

NFC doesn't work

reclaimerx10, 2025-02-16:
I just bought and got mine but the NFC does not work at all. Tested the cards I have with my phone and work there but won't read on the t-embed. Trying customer support but no response yet.

TheDuc, 2025-02-17:
How did you manage to fix this?

reclaimerx10, 2025-02-17:
User error actually, I thought the antenna was on the rounded area on the side but it is actually on the bottom and you need to hold the card in the right spot for it to read. It's the smaller black rectangle if you have the see through case in the middle

Closed 2025-02-16.

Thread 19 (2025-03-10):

Can't read EMV card

andreock, 2025-03-10:
Hi, the antenna of the PN532 mounted on T-Embed-CC1101 can't read EMV card besides they are ISO14443A/B compliant(13.56MHz). For example popular Elechouse PN532 can read this type of card so it's not a chip issue but probably an issue with antenna length.

Closed 2025-04-24.

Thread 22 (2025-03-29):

MICRO SD CARD won't mount; won't even detect.

Enrique956, 2025-03-29:
Will not mount to device, connected to another device.

Closed 2025-05-13.

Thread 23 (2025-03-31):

Is it possible to replace the screen?

th1s-david, 2025-03-31:
Hello,

My display broke in my pocket while moving the device
Is it possible to replace the display?

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

ShallowGreen123, 2025-04-07:
Hello, where did you buy it from, just contact the customer service there to help you replace the screen or replace the device.

th1s-david, 2025-04-07:
I've ordered a new screen and I'll install it myself since I disassembled the device

Closed 2025-05-22.

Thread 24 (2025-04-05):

sd card slot issue

Likhith124, 2025-04-05:
my lylogo t emebd is not recognising my sd card after some time of putting it in . it recognises it back if if remove it and put it  in again

Closed 2025-05-20.

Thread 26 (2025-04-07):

Broken T-Embed-CC1101 screen

E-Vitality, 2025-04-07:
I broke my screen is there a way to replace it? where can I buy a new screen ?

ShallowGreen123, 2025-04-07:
Can you contact the customer service of the website to see if they can replace the screen or replace the device?

E-Vitality, 2025-04-07:
Can't find the email of their custumer service.

th1s-david, 2025-04-09:
You can open it with the 2 screws and if you carefully get the board off the clips, I replaced mine today and this screen worked:

https://a.aliexpress.com/_EJ00qrS

E-Vitality, 2025-04-09:
Ok, thanks

Closed 2025-05-24.

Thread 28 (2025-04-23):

Emulating NFC Tags does not work

K0IN, 2025-04-23:
When running the example code for emulating a tag, i always run into this issue:

```
[  3970][E][Wire.cpp:513] requestFrom(): i2cRead returned Error 263
[...]
```

Code:
https://github.com/Xinyuan-LilyGO/T-Embed-CC1101/blob/master/examples/pn532_emulatetag/pn532_emulatetag.ino

run4type, 2025-05-11:
Did you find a way to emulate?

K0IN, 2025-05-21:
> Did you find a way to emulate?

no, do you have the same error?  (I was thinking maybe my hardware is defect)

K0IN, 2025-06-24:
bump

Huzzla101, 2025-07-25:
So what kind of SW are you using to try to emulate, you also have a
chameleon etc that you connect to ? Are you sure that the pinouts are
properly connected according to the SW you using ?

On Fri, Jul 25, 2025 at 5:19 AM github-actions[bot] <
***@***.***> wrote:

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

--
Kind Regards

C.R

May Prosperity allways be with us!!

Closed 2025-09-10.

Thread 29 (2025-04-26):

Wheel issue on my T-embed

Kotok7, 2025-04-26:
I have t-embed cc1101 for over 2 months now, but suddenly my wheel started to scroll things by itself in random directions. And it's not a firmware bug, because I tested 4 firmwares and nothing changed, so it's a hardware issue. Here's the video where that issue is clearly visible on official firmware. Please tell me what I need to do to repair this. https://github.com/user-attachments/assets/7fdf52ea-d06c-4676-9147-c2798c64fb54

IgnasFalcon, 2025-05-08:
I had a similar problem.

Kotok7, 2025-05-08:
I just cleaned it and it works, nevermind

IgnasFalcon, 2025-05-08:
Cool! How did you clean it though?
________________________________
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

Kotok7, 2025-05-09:
I just completely took the wheel apart, blew on it to get rid of the dust, and put it back together.

IgnasFalcon, 2025-05-13:
How did you take it of? Can you give a link to a video that shows taking them off an encoder?

Perelol, 2025-05-15:
Just pull it off clean using Isopropyl alcohol and re assemble pulling heads dome force don't lose black piece inside it just take it off face facing up

Kotok7, 2025-05-17:
> How did you take it of? Can you give a link to a video that shows taking them off an encoder?

I don't have any video. I just unscrewed everything and cleaned it, it's very easy to do

Closed 2025-05-08.

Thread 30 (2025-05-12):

Adding an NRF24 module and 2 external antennas on a custom 3D printed cover.

Mawa000, 2025-05-12:
I have installed an NRF GT-24 module on the T-Embed. Additionally, I have created a back cover to accommodate two external antennas in order to avoid drilling into the original case and to keep the aesthetics cleaner.

I have followed the assembly tutorial from this Reddit thread, which includes a video on YouTube. NOTE! There is a modification in the power connection, which is now done through the CC1101 and not through the ESP32.
https://www.reddit.com/r/LilyGO/comments/1k4u1ly/lilygo_tembed_nrf24_wiring/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

In the following link you can find the print files to do it yourselves:
https://www.printables.com/model/1293527-lilygo-t-embed-back-cover-for-two-antennas

Below I leave a few images as a guide of my installation process. In my case, I decided to use the same antenna for the original board's WIFI connection and the 2.4Ghz module while working on the same frequency. To do this, I used an SMA connector => 2 IPX.

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

Mawa000, 2025-05-14:
I finally changed the switch to use the IPX connector instead of the PCB antenna and it has improved the range. However, the coverage is still limited, but I suppose it is due to a hardware limitation.
I consider the issue resolved. In the future, I will try to install a higher power one like the E01-2G4M27D. I will keep you updated on the progress.

Mawa000, 2025-06-27:
> > Finalmente cambié el interruptor para usar el conector IPX en lugar de la antena PCB y ha mejorado el alcance. Sin embargo, la cobertura sigue siendo limitada, pero supongo que se debe a una limitación de hardware. Doy por resuelto el problema. En el futuro, intentaré instalar uno de mayor potencia como el E01-2G4M27D. Os mantendré informados sobre el progreso.
>
> ¿Se puede enviar una foto de cómo está GT24 después de cambiar para usar la antena externa?

I don't understand you. Do you mean how to connect the antennas to each connector?

breadDOA, 2025-06-27:
I didn't understand how to enable the outer antenna, have to do a jumper in 1 and 3? Is there a photo?

Mawa000, 2025-06-27:
> I didn't understand how to enable the outer antenna, have to do a jumper in 1 and 3? Is there a photo?

Ahhh! Okay, now I understand!
Yes. There are three connection points, 1, 2, ad 3. By default, it comes with an element (I don't know if it's a coil or a simple jumper) soldered between points 1 and 2. You must remove it and re-solder it between points 1 and 3. Point 1 is the center.

breadDOA, 2025-06-28:
But to weld in 1 and 3 I would need a "jumper" bigger than what comes in it, didn't you? Honestly I don't know how to do this

Mawa000, 2025-06-28:
> But to weld in 1 and 3 I would need a "jumper" bigger than what comes in it, didn't you? Honestly I don't know how to do this

Not in my case. The element is very small, but two drops of tin should be enough. I did it this way. But as I said, you have to be very patient and steady, because the element is very small. If you lose it for whatever reason, try making a tin bridge. If it's just a jumper, it should work.
You must move the jumper in the image to the position indicated by the arrows. The distance between the center and outer contacts is the same.

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

breadDOA, 2025-06-28:
The "metal" of the photo has to be expanded to pass over the contact 2 to be between 1 and 3 but not 2? Or just pass the estio in all 3, I'm not sure how to do this, you did not do it in yours?

breadDOA, 2025-06-28:
Can you record a video explaining or showing how to do it?

Mawa000, 2025-06-28:
> Can you record a video explaining or showing how to do it?

Sorry, but I think I can make a video.
It's simple. Right now, there's an SMD component (the one below the arrows I drew) that connects the center point and the point that goes to the PCB antenna (the copper track that makes a loop). You must remove it and re-solder it between the center point and the point I indicated with the green arrow, on the opposite side of the current one. The point on the PCB antenna board should not be connected anywhere.
Technically, it's a physical switch, connecting the center point to one end or the other. When you're done, if you've done it correctly, there should be electrical continuity between that component and the center pin of the IPX connector, but not with the PCB antenna. If you're not entirely sure what I'm explaining, I think it would be advisable to have someone with more experience do the installation for you.

Closed 2025-05-14.

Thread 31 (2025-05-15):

Low Wifi range

peppemas1, 2025-05-15:
hi, i put an external antenna on my t-embed cc1101 and all work fine with firmware bruce, but now i have noticed problem on wifi strenght, i have try to change antenna, reconnect the original , change firmware(capibara and original fw), but nothing, signal streght is decreased, in the same spot i find only 2 network and before more of 6, all network are always persent i repeat the test with a smartphone and an m5stick and i see the all wifi netw. How i can do ? how i can hard reset the device?

peppemas1, 2025-05-16:
Please answer, i can try this guide by espressif for factory reset esp32:

https://www.youtube.com/watch?v=3oEvXhgHZHo&t=198s

ShallowGreen123, 2025-05-16:
Adjust the transmission power: Set the power to the maximum value (such as 20dBm) through `esp_wifi_set_max_tx_power()`;

The general method to increase the receiving power is to replace the antenna with a better performance one. The surface mount antenna used in this product may not have as good performance parameters as the rubber rod antenna.

peppemas1, 2025-05-16:
the original antenna was replaced with external antenna mod ( i use a 3dbi antenna) , everything was working fine until a few days ago. But for a few days i have noticed low signal in receiver mode, i use bruce firmware , when do a wifi network scan i found only my  network with poor signal -70 near the modem ( 1 meter distance) , before in the same spot i found other wifi network near me, if i do the search by a smarphone or a m5stick i found the other network . If i use evil portal in bruce firmware , work perfect at long distance. The problem is only in wifi receiver mode

peppemas1, 2025-05-19:
> gh `esp_wifi_set_max_tx_power()`;

hi, how i can send this command to esp32, is possible via web

ShallowGreen123, 2025-05-20:
Hello, you can contact the customer service and ask them to send you a new WIFI antenna；

Closed 2025-05-20.

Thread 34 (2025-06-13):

Selection wheel failure. (Solved)

Mawa000, 2025-06-13:
I know that some of you have had trouble with the wheel over time, so I'm going to tell you how I fixed it.

In my case, the wheel was skipping steps and behaving randomly. The solution was to clean it internally with isopropyl alcohol. To do this, you need to disassemble it as follows:
1. Remove the rear and side covers, disconnecting all the antennas and the battery first.
2. Once you're working only with the module, remove the two screws shown in the image and separate the board from the frame by unclipping the tabs marked in the image.
3. After removing the frame, carefully pry the rotary button from underneath to release some clips and access the interior. Be careful—the central button has a small loose piece that can fall out and is easy to lose.
4. Thoroughly clean the contacts on both the wheel and the tracks on the part of the wheel that's soldered to the board.
5. Reassemble everything by reversing the steps above.

I’ve included a photo where I mark the correspondence of the button contacts. I think implementing push buttons would be feasible if the wheel ever breaks down completely. I don’t fully understand how it works, but I believe it's based on sending 0s and 1s by bridging tracks 1 and 2 with the GND track.

If we manage to get a working circuit diagram, I could design a 3D-printed housing for buttons (I think 3 would be enough: UP, DOWN, and OK) to fit in place of the wheel. It would definitely be a more reliable, though slightly slower, solution.

Hope it helps!

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

Closed 2025-06-13.

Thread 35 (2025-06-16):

Please Confirm IPEX Connector positions.

JimikoSK, 2025-06-16:
Hi there, when I opened the device the glue on the battery pulled up the IPEX connectors.

Can someone please tell me if these are correct?

1 - Curls around the curve of the case.
2 - Goes up to near the IR lens.
3 - Goes to the NFC rectangle.

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

JimikoSK, 2025-06-16:
@ShallowGreen123 Thank you. 💕

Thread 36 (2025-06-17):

The backlight is on, but no content is shown on the display.

hoanb1, 2025-06-17:
Dear LilyGO Support Team,

I recently purchased a new LilyGO T-Embed CC1101 device through an online individual seller. While the device appears to be functioning in most aspects—buttons are responsive and I can see output through the serial monitor—the screen is not displaying anything. The backlight is on, but no content is shown on the display.

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

I have not modified the hardware, and all other components seem to be working normally. I would appreciate your assistance in diagnosing and resolving this issue.

Thank you in advance for your support.

ShallowGreen123, 2025-06-18:
1. You can try the individual screen test program first，[display_test](https://github.com/Xinyuan-LilyGO/T-Embed-CC1101/tree/master/examples/display_test)

2. It might be due to poor screen contact. You can try disassembling the device and reinserting the screen's ribbon cable to see if it works.

3. If the screen still has problems after operating in the above way, you need to contact the merchant to replace it.

Huzzla101, 2025-06-18:
First try to use a toothpick and push the RST (reset) button that is on the
upper left side of battery , u dont have to remove battery but make sure u
get a tick when pushing the button... That will reset and may reboot screen
to work... IF that dont work then try to hold the POWER button on the upper
right side of the battery and hold it down for 7seconds then release then
push reset again and see if anything, Then you should go for the solution
from Shallowgreen after if it doesnt work....

On Wed, Jun 18, 2025 at 4:23 AM ShallowGreen123 ***@***.***>
wrote:

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

--
Kind Regards

C.R

May Prosperity allways be with us!!

JudgeLP, 2025-07-18:
You are not the only one with this problem, and Lilygo Official Store at AliExpress is being informed about it: https://github.com/pr3y/Bruce/issues/1455

Closed 2025-09-02.

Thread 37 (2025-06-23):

record_test example not working on t-embed cc1101

ilker-aktuna, 2025-06-23:
I am trying to record from mic using the example "record_test" at:
https://github.com/Xinyuan-LilyGO/T-Embed-CC1101/tree/master/examples/record_test

however, nothing is being recorded (no files on the SD after 15 seconds, even after 30 seconds)

besides, it seems like it is going in a loop and does not end , because to troubleshoot I added log line :

        i2s_read((i2s_port_t)EXAMPLE_I2S_CH, (char *)i2s_readraw_buff, SAMPLE_SIZE, &bytes_read, 100);
        int sampleCount = bytes_read / 2;
    Serial.println(sampleCount);

it is writing continuously "0" to the serial.
So it can not go out of this loop:

while(flash_wr_size < flash_rec_time) {

and bytes_read is always 0

why ?

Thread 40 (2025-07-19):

Is there a way to utilize the tembed cc1101 board with my pc, I was wondering because of the black screen issue that my tembed has also went through?

mockme41, 2025-07-19:

peppemas1, 2025-07-28:
web ui trought firmware bruce

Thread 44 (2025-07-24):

Add instruction to upload /data to SPIFFS

iqfareez, 2025-07-24:
The README and the example code lacks instruction on how to upload data to SPIFFS of the ESP32. Some example, like `voice_test` may not running correctly without the required file.

Closed 2025-09-07.

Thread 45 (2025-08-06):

CC1101 Not Found in Bruce Firmware

Mysteriza, 2025-08-06:
I am having issues with the CC1101 module, which is now not functioning on Bruce Firmware and displays the message “CC1101 not found.” I suspect this is due to my carelessness and lack of knowledge when drilling into the case (without first removing the main board from the casing), and the intense vibrations caused the CC1101 to malfunction. Is there a solution to this issue? Or is it beyond repair?

Mysteriza, 2025-08-06:
I know everything was fine because when I first installed Bruce Firmware, everything was working properly, and the CC1101 was functioning well. The issue occured after I drilled into the case, and the intense vibrations during drilling somehow damaged the CC1101 module, causing it to no longer be detected by the Bruce Firmware. To confirm this, I also reinstalled the default firmware from T-Embed, but the result was the same—there was no response from the CC1101. That's why I'm certain the damage was caused by the drilling process.

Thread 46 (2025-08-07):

when i turn on first time appearing black screen and led lights on please help how to fix it ?

jatinsahu181, 2025-08-07:
when i turn on first time appearing black screen and led lights on please help how to fix it ?

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

Closed 2025-09-21.

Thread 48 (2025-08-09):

T-embed battery issue

Adam-neeeds-help, 2025-08-09:
I accidentally left my t-embed on charge most the day and not the battery is saying its 0%

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

jaylikesbunda, 2025-08-20:
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

sounds like a bruce issue?

Closed 2025-10-05.

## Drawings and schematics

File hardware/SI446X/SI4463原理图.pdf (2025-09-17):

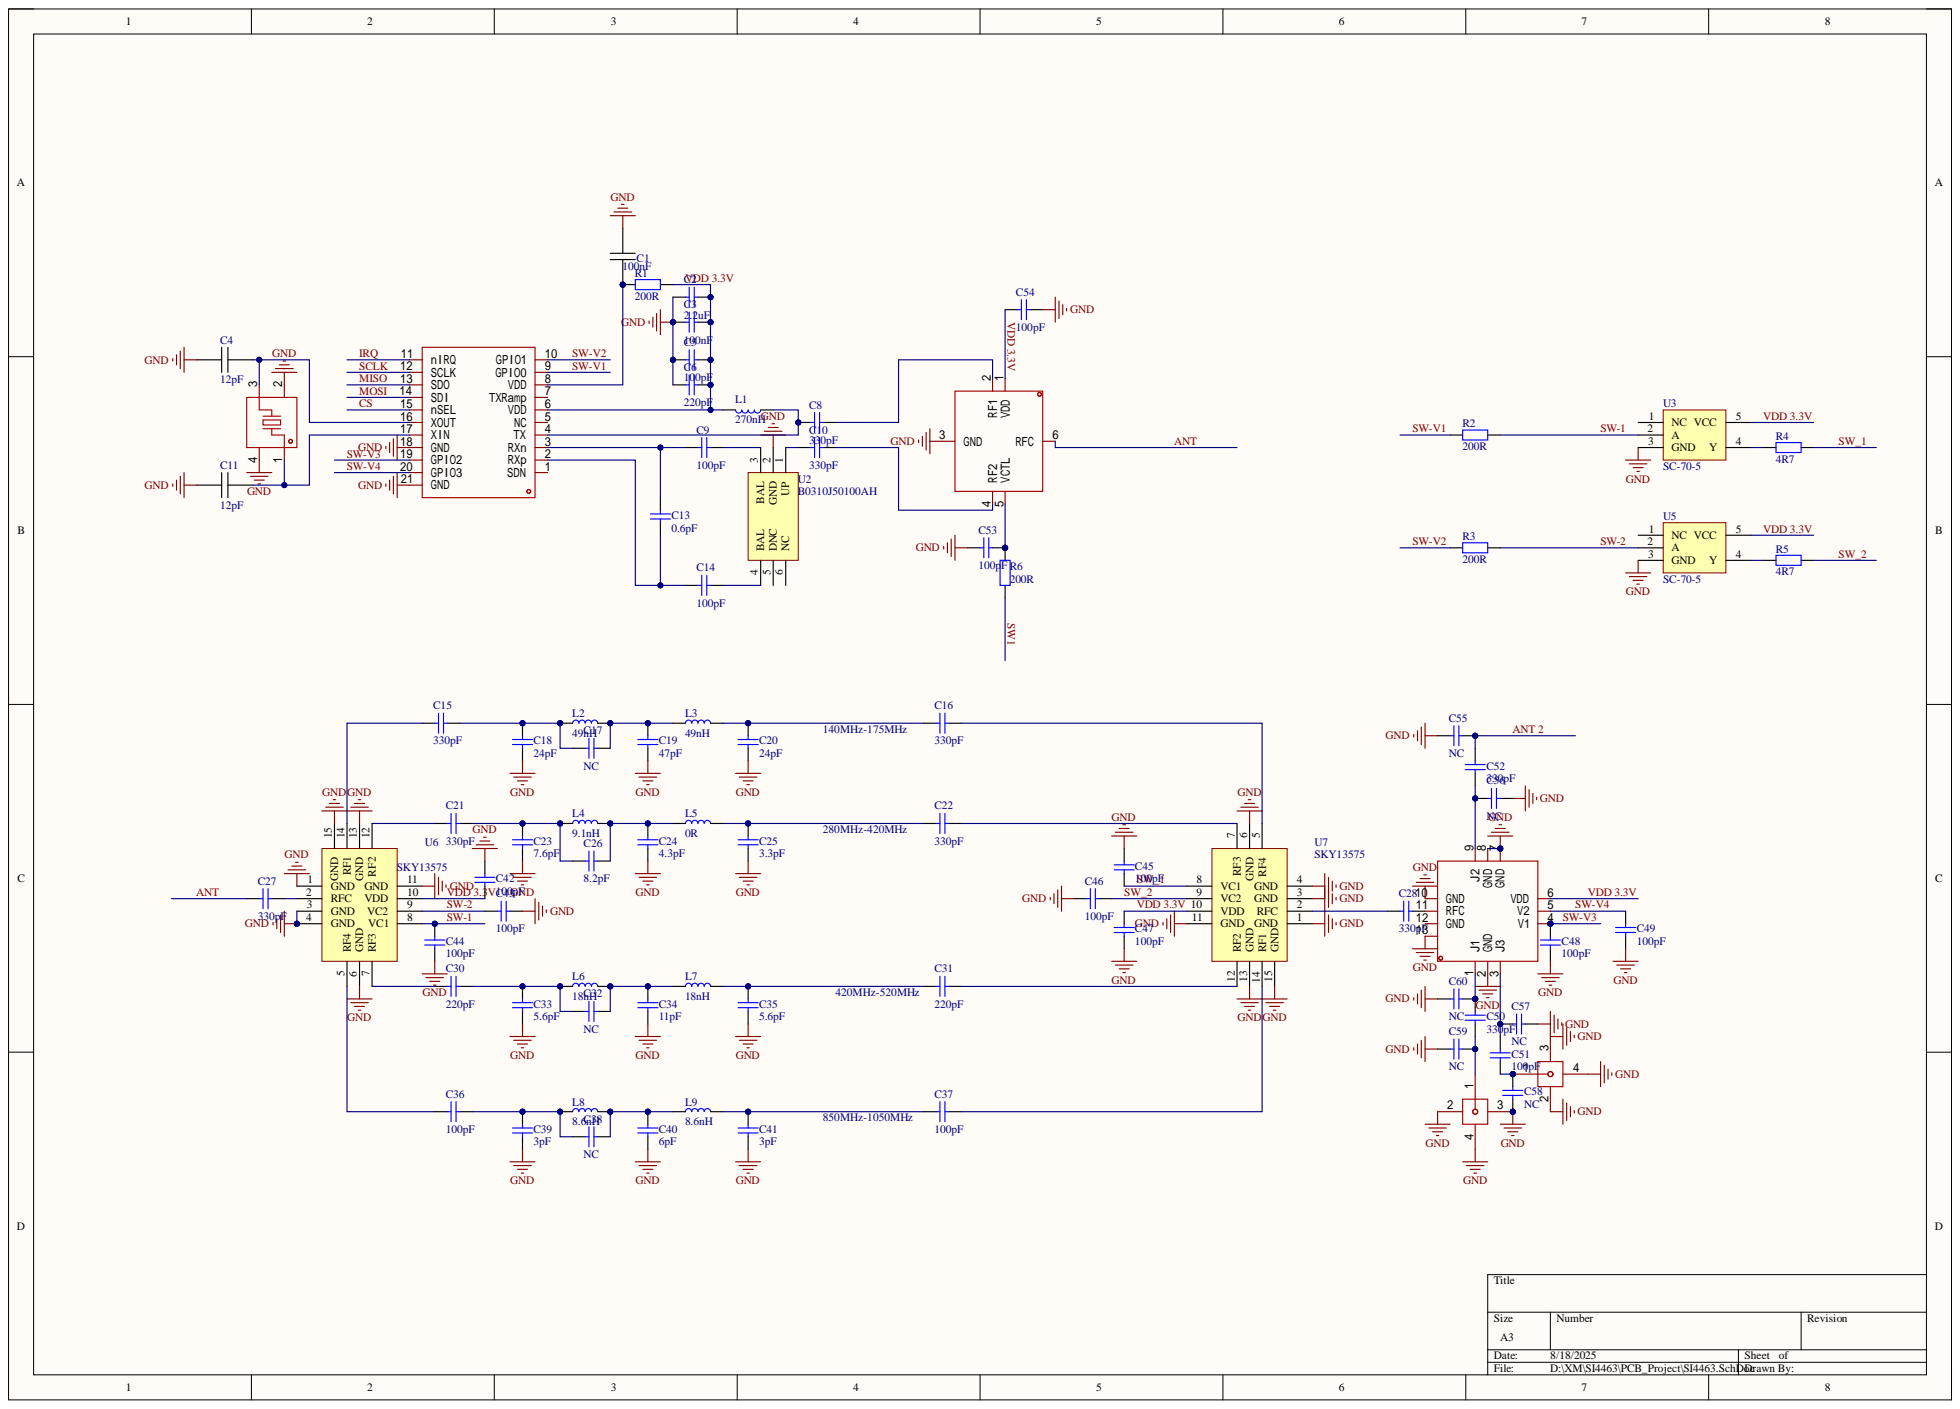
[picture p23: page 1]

UP 1 GND 2 BAL 3 BAL 4 DNC 5 NC 6

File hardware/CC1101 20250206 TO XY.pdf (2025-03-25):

6 | 5 | 4 | 3 | 2 | 1

D

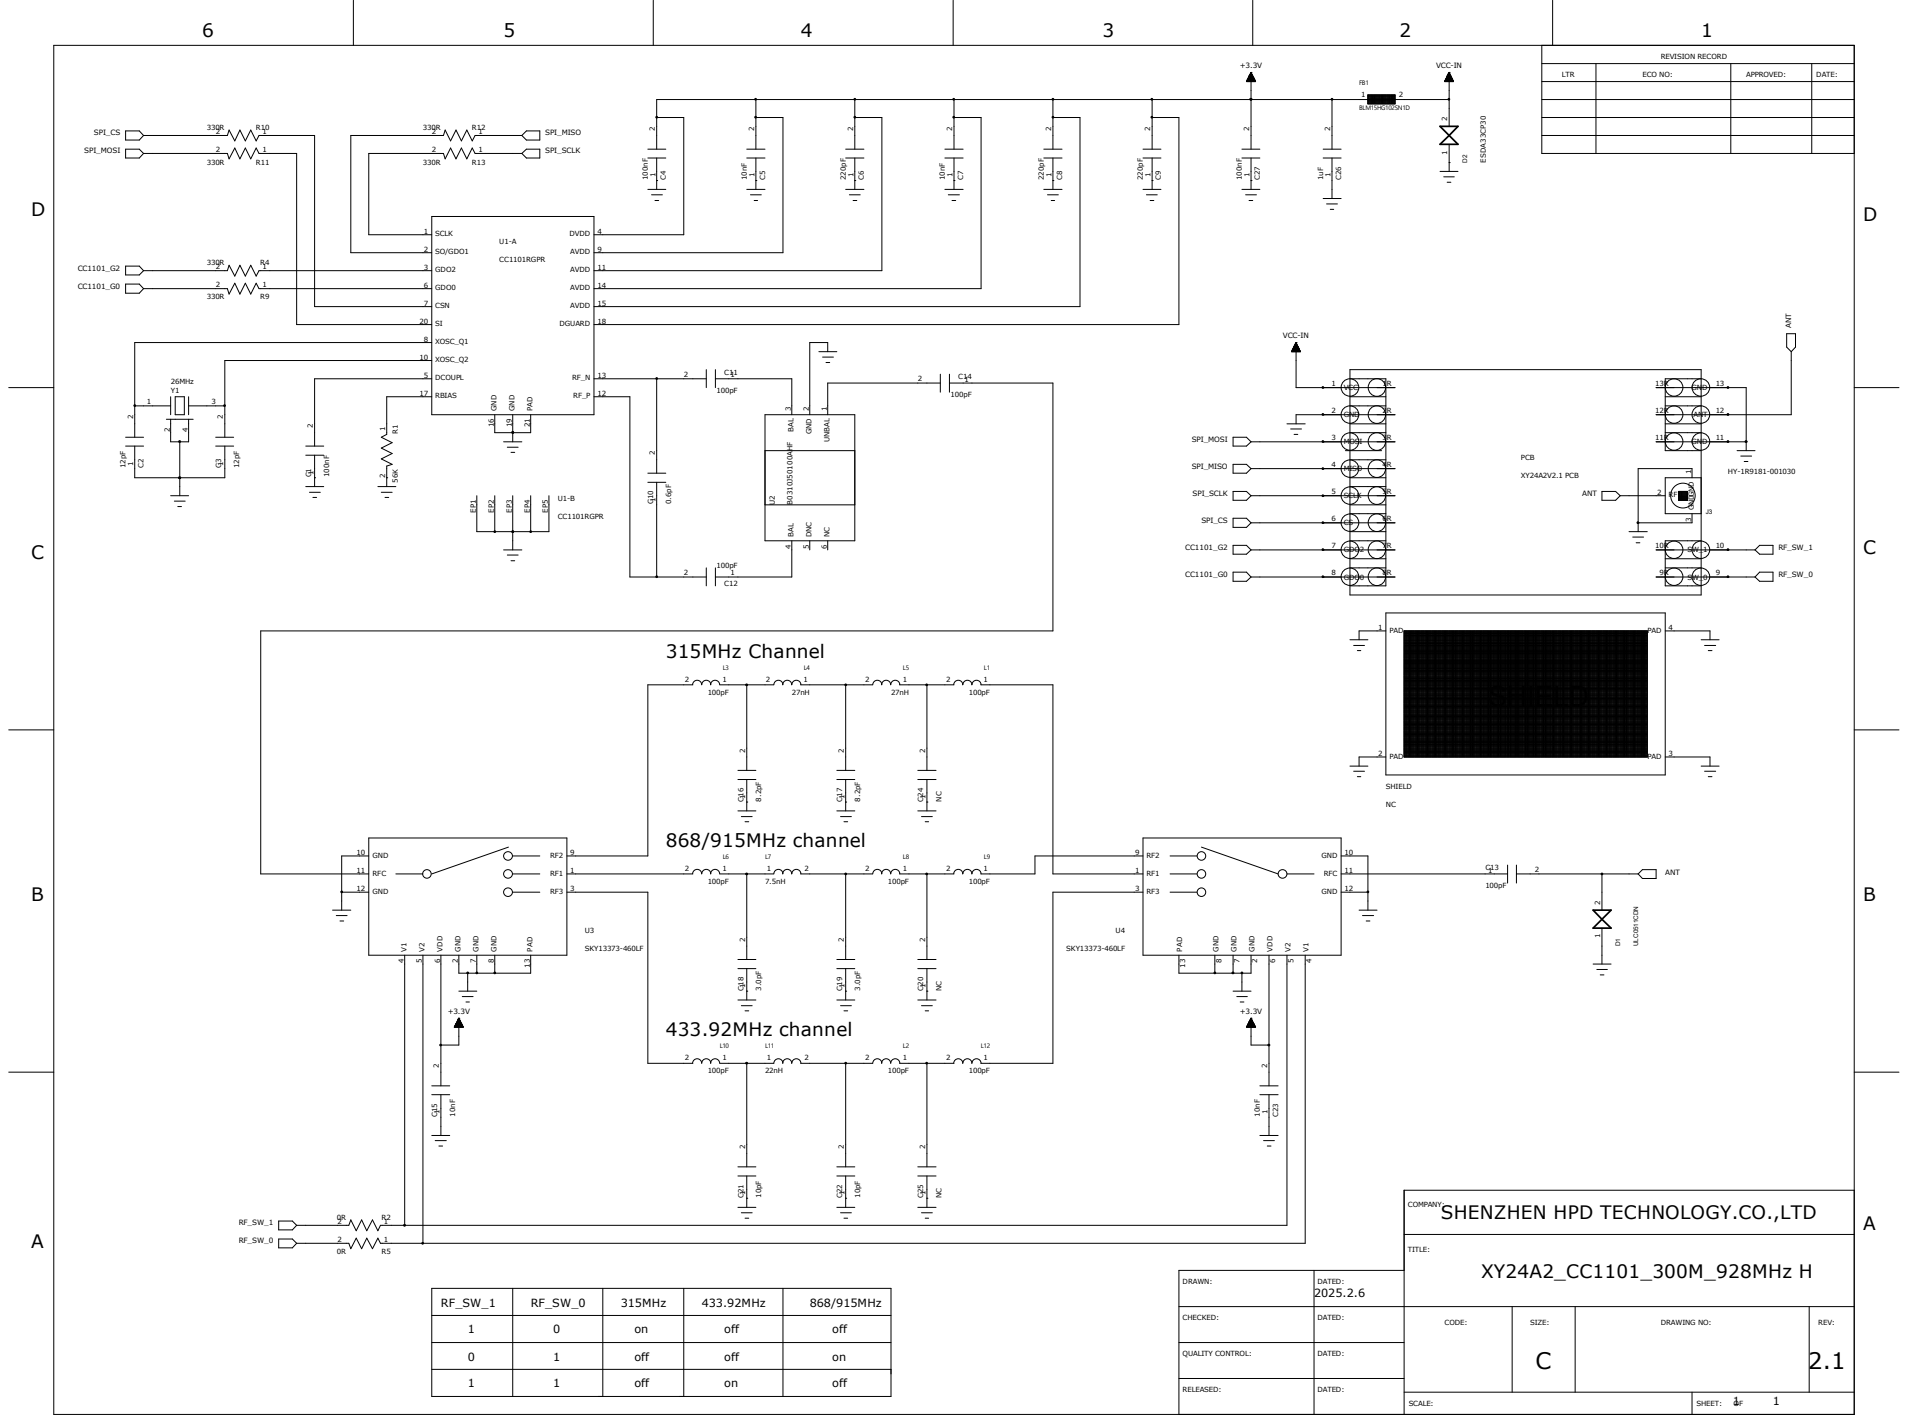
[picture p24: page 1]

VCC-IN | REVISION RECORD

LTR | | APPROVED: | DATE: ECO NO:

COMPANY:
SHENZHEN HPD TECHNOLOGY.CO.,LTD

DRAWN: | DATED: 2025.2.6
CHECKED: | DATED: | CODE: | SIZE: C | DRAWING NO: | REV: 2.1

RF_SW_1 | RF_SW_0 | 315MHz | 433.92MHz | 868/915MHz
1 0 | | on | off | off

1 1 | off | on | off

RELEASED: | DATED:

SCALE: | 1 1 SHEET: OF

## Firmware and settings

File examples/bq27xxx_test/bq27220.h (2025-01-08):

#ifndef BQ27227_H
#define BQ27227_H

#include "Arduino.h"
#include <Wire.h>
#include "bq27220_def.h"
#include "bq27220_data_memory.h"

#define DEFAULT_SCL  18
#define DEFAULT_SDA  8

typedef union ControlStatus{
    struct __reg
    {
        // Low byte, Low bit first
        uint8_t BATT_ID : 3; /**< Battery Identification */
        bool SNOOZE     : 1; /**< SNOOZE mode is enabled */
        bool BCA        : 1; /**< fuel gauge board calibration routine is active */
        bool CCA        : 1; /**< Coulomb Counter Calibration routine is active */
        uint8_t RSVD0   : 2; /**< Reserved */
        // High byte, Low bit first
        uint8_t RSVD1; /**< Reserved */
    } reg;
    uint16_t full;
} BQ27220ControlStatus;

typedef union BatteryStatus {
    struct __reg
    {
        // Low byte, Low bit first
        uint16_t DSG        : 1; /**< The device is in DISCHARGE */
        uint16_t SYSDWN     : 1; /**< System down bit indicating the system should shut down */
        uint16_t TDA        : 1; /**< Terminate Discharge Alarm */
        uint16_t BATTPRES   : 1; /**< Battery Present detected */
        uint16_t AUTH_GD    : 1; /**< Detect inserted battery */
        uint16_t OCVGD      : 1; /**< Good OCV measurement taken */
        uint16_t TCA        : 1; /**< Terminate Charge Alarm */
        uint16_t RSVD       : 1; /**< Reserved */
        // High byte, Low bit first
        uint16_t CHGING     : 1; /**< Charge inhibit */
        uint16_t FC         : 1; /**< Full-charged is detected */
        uint16_t OTD        : 1; /**< Overtemperature in discharge condition is detected */
        uint16_t OTC        : 1; /**< Overtemperature in charge condition is detected */
        uint16_t SLEEP      : 1; /**< Device is operating in SLEEP mode when set */
        uint16_t OCVFALL    : 1; /**< Status bit indicating that the OCV reading failed due to current */
        uint16_t OCVCOMP    : 1; /**< An OCV measurement update is complete */
        uint16_t FD         : 1; /**< Full-discharge is detected */
    } reg;
    uint16_t full;
}BQ27220BatteryStatus;

typedef enum {
    Bq27220OperationStatusSecSealed = 0b11,
    Bq27220OperationStatusSecUnsealed = 0b10,
    Bq27220OperationStatusSecFull = 0b01,
} Bq27220OperationStatusSec;

typedef union OperationStatus{
    struct __reg
    {
        // Low byte, Low bit first
        bool CALMD      : 1; /**< Calibration mode enabled */
        uint8_t SEC     : 2; /**< Current security access */
        bool EDV2       : 1; /**< EDV2 threshold exceeded */
        bool VDQ        : 1; /**< Indicates if Current discharge cycle is NOT qualified or qualified for an FCC updated */
        bool INITCOMP   : 1; /**< gauge initialization is complete */
        bool SMTH       : 1; /**< RemainingCapacity is scaled by smooth engine */
        bool BTPINT     : 1; /**< BTP threshold has been crossed */
        // High byte, Low bit first
        uint8_t RSVD1   : 2; /**< Reserved */
        bool CFGUPDATE  : 1; /**< Gauge is in CONFIG UPDATE mode */
        uint8_t RSVD0   : 5; /**< Reserved */
    } reg;
    uint16_t full;
} BQ27220OperationStatus;

typedef union GaugingStatus{
    struct __reg
    {
        // Low byte, Low bit first
        bool FD       : 1; /**< Full Discharge */
        bool FC       : 1; /**< Full Charge */
        bool TD       : 1; /**< Terminate Discharge */
        bool TC       : 1; /**< Terminate Charge */
        bool RSVD0    : 1; /**< Reserved */
        bool EDV      : 1; /**< Cell voltage is above or below EDV0 threshold */
        bool DSG      : 1; /**< DISCHARGE or RELAXATION */
        bool CF       : 1; /**< Battery conditioning is needed */
        // High byte, Low bit first
        uint8_t RSVD1 : 2; /**< Reserved */
        bool FCCX     : 1; /**< fcc1hz clock going into CC: 0 = 1 Hz, 1 = 16 Hz*/
        uint8_t RSVD2 : 2; /**< Reserved */
        bool EDV1     : 1; /**< Cell voltage is above or below EDV1 threshold */
        bool EDV2     : 1; /**< Cell voltage is above or below EDV2 threshold */
        bool VDQ      : 1; /**< Charge cycle FCC update qualification */
    } reg;
    uint16_t full;
} BQ27220GaugingStatus;

class BQ27220{
public:
    BQ27220() : addr{BQ27220_I2C_ADDRESS}, wire(&Wire), scl(DEFAULT_SCL), sda(DEFAULT_SDA)
    {}

    bool begin()
    {
        return wire->begin(DEFAULT_SDA, DEFAULT_SCL);
    }

    bool getIsCharging(void){
        BQ27220BatteryStatus batt;
        if(getBatteryStatus(&batt)) {
            return !batt.reg.DSG;
        }
        return false;
    }

    bool parameterCheck(uint16_t address, uint32_t value, size_t size, bool update);
    bool dateMemoryCheck(const BQ27220DMData *data_memory, bool update);

    bool init(const BQ27220DMData *data_memory = gauge_data_memory);
    bool reset(void);

    // Sealed Access
    bool sealAccess(void);
    bool unsealAccess(void);
    bool fullAccess(void);

    // get
    uint16_t getDeviceNumber(void);  // sub-commands
    uint16_t getVoltage(void);
    int16_t getCurrent(void);
    bool getControlStatus(BQ27220ControlStatus *ctrl_sta);
    bool getBatteryStatus(BQ27220BatteryStatus *batt_sta);
    bool getOperationStatus(BQ27220OperationStatus *oper_sta);
    bool getGaugingStatus(BQ27220GaugingStatus *gauging_sta);
    uint16_t getTemperature(void);
    uint16_t getFullChargeCapacity(void);
    uint16_t getDesignCapacity(void);
    uint16_t getRemainingCapacity(void);
    uint16_t getStateOfCharge(void);
    uint16_t getStateOfHealth(void);

    // i2c
    uint16_t readRegU16(uint16_t reg) {
        uint8_t data[2];
        i2cReadBytes(reg, data, 2);
        return ((uint16_t) data[1] << 8) | data[0];
    }

    // uint16_t readCtrlWord(uint16_t fun) {
    //     uint8_t msb = (fun >> 8);
    //     uint8_t lsb = (fun & 0x00FF);
    //     uint8_t cmd[2] = { lsb, msb };
    //     uint8_t data[2] = {0};

    //     i2cWriteBytes((uint8_t)BQ27220_COMMAND_CONTROL, cmd, 2);

    //     if (i2cReadBytes((uint8_t) 0, data, 2)) {
    //         return ((uint16_t)data[1] << 8) | data[0];
    //     }
    //     return 0;
    // }

    bool controlSubCmd(uint16_t sub_cmd)
    {
        uint8_t msb = (sub_cmd >> 8);
        uint8_t lsb = (sub_cmd & 0x00FF);
        uint8_t buf[2] = { lsb, msb };
        i2cWriteBytes(CommandControl, buf, 2);
        return true;
    }

    bool i2cReadBytes(uint8_t reg, uint8_t * dest, uint8_t count) {
        wire->beginTransmission(addr);
        wire->write(reg);
        wire->endTransmission(true);

        wire->requestFrom(addr, count);
        for(int i = 0; i < count; i++) {
            dest[i] = wire->read();
        }
        return true;
    }

    bool i2cWriteBytes(uint8_t reg, uint8_t * src, uint8_t count) {
        wire->beginTransmission(addr);
        wire->write(reg);
        for(int i = 0; i < count; i++) {
            wire->write(src[i]);
        }
        wire->endTransmission(true);
        return true;
    }

private:
    TwoWire *wire = NULL;
    uint8_t addr = 0;
    int scl = -1;
    int sda = -1;
    BQ27220BatteryStatus bat_st;
};

#endif

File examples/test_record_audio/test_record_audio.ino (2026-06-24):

#include <Arduino.h>
#include <FS.h>
#include <SD.h>
#include <SPI.h>
#include <TFT_eSPI.h>
#include <RotaryEncoder.h>
#include <driver/i2s.h>

#include "Audio.h"
#include "utilities.h"

namespace {

constexpr uint8_t kRotation = 3;
constexpr uint32_t kBusSettleMs = 20;
constexpr uint32_t kSdPowerSettleMs = 120;
constexpr uint32_t kSdRetryIntervalMs = 800;
constexpr uint32_t kUiFrameIntervalMs = 140;
constexpr uint32_t kButtonDebounceMs = 30;

constexpr i2s_port_t kMicPort = I2S_NUM_0;
constexpr i2s_port_t kSpeakerPort = I2S_NUM_1;
constexpr uint32_t kSampleRate = 16000;
constexpr uint8_t kBitsPerSample = 16;
constexpr uint8_t kNumChannels = 1;
constexpr uint32_t kRecordDurationSec = 10;
constexpr size_t kRecordChunkSamples = 512;
constexpr size_t kRecordChunkBytes = kRecordChunkSamples * sizeof(int16_t);
constexpr size_t kWavHeaderSize = 44;
constexpr uint32_t kRecordDataBytes =
    kSampleRate * (kBitsPerSample / 8U) * kNumChannels * kRecordDurationSec;

constexpr uint32_t kSdMountFrequencies[] = {10000000UL, 4000000UL, 1000000UL};
constexpr char kRecordPath[] = "/record.wav";
constexpr uint8_t kAudioVolume = 21;
constexpr uint8_t kRecordGain = 2;

constexpr uint16_t kColorBg = 0x0841;
constexpr uint16_t kColorPanel = 0x1082;
constexpr uint16_t kColorPanelEdge = 0x31A6;
constexpr uint16_t kColorCard = 0x18C3;
constexpr uint16_t kColorPassBg = 0x0A41;
constexpr uint16_t kColorFailBg = 0x3006;
constexpr uint16_t kColorActiveBg = 0x1247;

enum class State : uint8_t {
    WAIT_SD = 0,
    RECORDING,
    READY,
    PLAYING,
    ERROR,
};

enum class CardState : uint8_t {
    WAIT = 0,
    ACTIVE,
    PASS,
    FAIL,
};

enum class FailureOrigin : uint8_t {
    NONE = 0,
    RECORD,
    PLAYBACK,
};

enum class RecordResult : uint8_t {
    SUCCESS = 0,
    RESTART,
    NO_SD,
    FAILURE,
};

struct DebouncedButton {
    explicit DebouncedButton(uint8_t pinNumber) : pin(pinNumber) {}

    void begin()
    {
        pinMode(pin, INPUT_PULLUP);
        rawState = digitalRead(pin);
        stableState = rawState;
        lastChangeMs = millis();
    }

    bool pressed()
    {
        const bool currentRaw = digitalRead(pin);
        const uint32_t now = millis();

        if (currentRaw != rawState) {
            rawState = currentRaw;
            lastChangeMs = now;
        }

        if ((now - lastChangeMs) >= kButtonDebounceMs && stableState != rawState) {
            stableState = rawState;
            if (stableState == LOW) {
                return true;
            }
        }

        return false;
    }

    uint8_t pin;
    bool rawState = HIGH;
    bool stableState = HIGH;
    uint32_t lastChangeMs = 0;
};

TFT_eSPI tft;
TFT_eSprite canvas(&tft);
RotaryEncoder encoder(ENCODER_INA, ENCODER_INB, RotaryEncoder::LatchMode::TWO03);
Audio audio(false, 3, kSpeakerPort);
DebouncedButton userButton(BOARD_USER_KEY);
DebouncedButton encoderButton(ENCODER_KEY);

State gState = State::WAIT_SD;
FailureOrigin gFailureOrigin = FailureOrigin::NONE;
uint32_t gStateEnterMs = 0;
uint32_t gLastUiDrawMs = 0;
uint32_t gLastSdProbeMs = 0;
bool gScreenDirty = true;
bool gCanvasReady = false;
bool gSdMounted = false;
bool gHasRecording = false;
uint32_t gMountedFrequency = 0;
uint64_t gCardTotalMB = 0;
uint64_t gCardUsedMB = 0;
uint32_t gRecordBytesWritten = 0;
uint32_t gRecordedFileSize = 0;
uint16_t gRecordRms = 0;
uint16_t gRecordPeak = 0;
uint8_t gMenuIndex = 0;
long gLastEncoderPosition = 0;
char gErrorTitle[48] = {0};
char gErrorDetail[96] = {0};

void redrawScreen();

void deselectSharedSpiDevices()
{
    pinMode(DISPLAY_CS, OUTPUT);
    digitalWrite(DISPLAY_CS, HIGH);

    pinMode(BOARD_SD_CS, OUTPUT);
    digitalWrite(BOARD_SD_CS, HIGH);

    pinMode(BOARD_LORA_CS, OUTPUT);
    digitalWrite(BOARD_LORA_CS, HIGH);

    pinMode(BOARD_NRF24_CS, OUTPUT);
    digitalWrite(BOARD_NRF24_CS, HIGH);
}

SPIClass &sharedSpi()
{
    return tft.getSPIinstance();
}

void markDirty()
{
    gScreenDirty = true;
}

void resetEncoderSelection(uint8_t index)
{
    gMenuIndex = index % 2U;
    encoder.setPosition(gMenuIndex);
    gLastEncoderPosition = gMenuIndex;
    markDirty();
}

void clearFailure()
{
    gFailureOrigin = FailureOrigin::NONE;
    gErrorTitle[0] = '\0';
    gErrorDetail[0] = '\0';
}

void setState(State state)
{
    gState = state;
    gStateEnterMs = millis();
    markDirty();
}

void setError(FailureOrigin origin, const char *title, const char *detail)
{
    gFailureOrigin = origin;
    strncpy(gErrorTitle, title, sizeof(gErrorTitle) - 1U);
    gErrorTitle[sizeof(gErrorTitle) - 1U] = '\0';
    strncpy(gErrorDetail, detail, sizeof(gErrorDetail) - 1U);
    gErrorDetail[sizeof(gErrorDetail) - 1U] = '\0';
    setState(State::ERROR);
}

bool initDisplayPower()
{
    pinMode(BOARD_PWR_EN, OUTPUT);
    digitalWrite(BOARD_PWR_EN, HIGH);

    deselectSharedSpiDevices();
    delay(kBusSettleMs);

    pinMode(DISPLAY_BL, OUTPUT);
    digitalWrite(DISPLAY_BL, LOW);

    tft.begin();
    tft.setRotation(kRotation);
    tft.fillScreen(TFT_BLACK);

    digitalWrite(DISPLAY_BL, HIGH);
    return true;
}

bool mountSdCard(uint32_t &mountedFrequency)
{
    pinMode(BOARD_SD_CS, OUTPUT);
    digitalWrite(BOARD_SD_CS, HIGH);
    delay(kSdPowerSettleMs);

    for (const uint32_t frequency : kSdMountFrequencies) {
        SD.end();
        deselectSharedSpiDevices();
        delay(kBusSettleMs);

        if (!SD.begin(BOARD_SD_CS, sharedSpi(), frequency)) {
            continue;
        }

        if (SD.cardType() == CARD_NONE) {
            SD.end();
            continue;
        }

        mountedFrequency = frequency;
        return true;
    }

    mountedFrequency = 0;
    return false;
}

void clearSdInfo()
{
    gSdMounted = false;
    gMountedFrequency = 0;
    gCardTotalMB = 0;
    gCardUsedMB = 0;
}

bool sdAccessible()
{
    if (!gSdMounted) {
        return false;
    }

    File root = SD.open("/");
    if (!root) {
        return false;
    }

    root.close();
    return true;
}

void refreshSdStats()
{
    if (!gSdMounted) {
        return;
    }

    gCardTotalMB = SD.totalBytes() / (1024ULL * 1024ULL);
    gCardUsedMB = SD.usedBytes() / (1024ULL * 1024ULL);
}

bool ensureSdMounted()
{
    if (sdAccessible()) {
        return true;
    }

    clearSdInfo();

    uint32_t mountedFrequency = 0;
    if (!mountSdCard(mountedFrequency)) {
        return false;
    }

    gSdMounted = true;
    gMountedFrequency = mountedFrequency;
    refreshSdStats();
    return true;
}

String formatBytes(uint32_t bytes)
{
    if (bytes >= 1024UL * 1024UL) {
        return String(static_cast<float>(bytes) / (1024.0f * 1024.0f), 1) + "M";
    }
    if (bytes >= 1024UL) {
        return String((bytes + 512UL) / 1024UL) + "K";
    }
    return String(bytes) + "B";
}

uint32_t recordElapsedMs()
{
    return (gRecordBytesWritten * 1000UL) /
           (kSampleRate * kNumChannels * (kBitsPerSample / 8U));
}

uint16_t recordProgressPercent()
{
    if (kRecordDataBytes == 0) {
        return 0;
    }

    const uint32_t progress = (gRecordBytesWritten * 100UL) / kRecordDataBytes;
    return progress > 100U ? 100U : static_cast<uint16_t>(progress);
}

uint16_t computeRms(const int16_t *samples, size_t count)
{
    if (count == 0) {
        return 0;
    }

    int64_t sum = 0;
    for (size_t index = 0; index < count; ++index) {
        const int32_t sample = samples[index];
        sum += sample * sample;
    }

    return static_cast<uint16_t>(sqrt(static_cast<double>(sum) / count));
}

int16_t applySampleGain(int16_t sample)
{
    int32_t scaled = static_cast<int32_t>(sample) * kRecordGain;
    if (scaled > INT16_MAX) {
        scaled = INT16_MAX;
    } else if (scaled < INT16_MIN) {
        scaled = INT16_MIN;
    }
    return static_cast<int16_t>(scaled);
}

void generateWavHeader(uint8_t *wavHeader, uint32_t wavSize)
{
    const uint32_t fileSize = wavSize + kWavHeaderSize - 8U;
    const uint32_t byteRate = kSampleRate * (kBitsPerSample / 8U) * kNumChannels;
    const uint16_t blockAlign = (kBitsPerSample / 8U) * kNumChannels;

    const uint8_t header[kWavHeaderSize] = {
        'R', 'I', 'F', 'F',
        static_cast<uint8_t>(fileSize & 0xFF),
        static_cast<uint8_t>((fileSize >> 8) & 0xFF),
        static_cast<uint8_t>((fileSize >> 16) & 0xFF),
        static_cast<uint8_t>((fileSize >> 24) & 0xFF),
        'W', 'A', 'V', 'E',
        'f', 'm', 't', ' ',
        0x10, 0x00, 0x00, 0x00,
        0x01, 0x00,
        static_cast<uint8_t>(kNumChannels), 0x00,
        static_cast<uint8_t>(kSampleRate & 0xFF),
        static_cast<uint8_t>((kSampleRate >> 8) & 0xFF),
        static_cast<uint8_t>((kSampleRate >> 16) & 0xFF),
        static_cast<uint8_t>((kSampleRate >> 24) & 0xFF),
        static_cast<uint8_t>(byteRate & 0xFF),
        static_cast<uint8_t>((byteRate >> 8) & 0xFF),
        static_cast<uint8_t>((byteRate >> 16) & 0xFF),
        static_cast<uint8_t>((byteRate >> 24) & 0xFF),
        static_cast<uint8_t>(blockAlign & 0xFF),
        static_cast<uint8_t>((blockAlign >> 8) & 0xFF),
        static_cast<uint8_t>(kBitsPerSample), 0x00,
        'd', 'a', 't', 'a',
        static_cast<uint8_t>(wavSize & 0xFF),
        static_cast<uint8_t>((wavSize >> 8) & 0xFF),
        static_cast<uint8_t>((wavSize >> 16) & 0xFF),
        static_cast<uint8_t>((wavSize >> 24) & 0xFF),
    };

    memcpy(wavHeader, header, sizeof(header));
}

bool initMic()
{
    i2s_config_t config = {};
    config.mode = static_cast<i2s_mode_t>(I2S_MODE_MASTER | I2S_MODE_RX | I2S_MODE_PDM);
    config.sample_rate = kSampleRate;
    config.bits_per_sample = I2S_BITS_PER_SAMPLE_16BIT;
    config.channel_format = I2S_CHANNEL_FMT_ONLY_LEFT;
    config.communication_format = I2S_COMM_FORMAT_STAND_I2S;
    config.intr_alloc_flags = ESP_INTR_FLAG_LEVEL2;
    config.dma_buf_count = 8;
    config.dma_buf_len = 200;
    config.use_apll = false;
    config.tx_desc_auto_clear = false;
    config.fixed_mclk = 0;

    i2s_pin_config_t pins = {};
    pins.mck_io_num = I2S_PIN_NO_CHANGE;
    pins.bck_io_num = I2S_PIN_NO_CHANGE;
    pins.ws_io_num = BOARD_MIC_CLK;
    pins.data_out_num = I2S_PIN_NO_CHANGE;
    pins.data_in_num = BOARD_MIC_DATA;

    i2s_driver_uninstall(kMicPort);

    if (i2s_driver_install(kMicPort, &config, 0, nullptr) != ESP_OK) {
        return false;
    }
    if (i2s_set_pin(kMicPort, &pins) != ESP_OK) {
        i2s_driver_uninstall(kMicPort);
        return false;
    }
    if (i2s_set_clk(kMicPort, kSampleRate, I2S_BITS_PER_SAMPLE_16BIT, I2S_CHANNEL_MONO) != ESP_OK) {
        i2s_driver_uninstall(kMicPort);
        return false;
    }

    i2s_zero_dma_buffer(kMicPort);
    return true;
}

void deinitMic()
{
    i2s_driver_uninstall(kMicPort);
}

void stopPlayback(bool backToReady)
{
    if (audio.isRunning()) {
        audio.stopSong();
        delay(kBusSettleMs);
    }

    if (backToReady && gSdMounted) {
        setState(State::READY);
        resetEncoderSelection(0);
    }
}

bool startPlayback()
{
    if (!gHasRecording) {
        setError(FailureOrigin::PLAYBACK, "No recording available",
                 "Please record a new 10 second clip first.");
        return false;
    }

    if (!ensureSdMounted()) {
        setState(State::WAIT_SD);
        return false;
    }

    stopPlayback(false);

    if (!SD.exists(kRecordPath)) {
        gHasRecording = false;
        gRecordedFileSize = 0;
        setError(FailureOrigin::PLAYBACK, "record.wav missing",
                 "Insert SD card and record a new sample.");
        return false;
    }

    if (!audio.connecttoFS(SD, kRecordPath)) {
        setError(FailureOrigin::PLAYBACK, "Playback start failed",
                 "Audio could not open the WAV file from SD.");
        return false;
    }

    clearFailure();
    setState(State::PLAYING);
    resetEncoderSelection(0);
    Serial.println(F("[PLAY] Playing /record.wav"));
    return true;
}

RecordResult recordOnce()
{
    if (!ensureSdMounted()) {
        return RecordResult::NO_SD;
    }

    if (!initMic()) {
        setError(FailureOrigin::RECORD, "Mic init failed",
                 "Unable to start the PDM microphone path.");
        return RecordResult::FAILURE;
    }

    if (SD.exists(kRecordPath)) {
        SD.remove(kRecordPath);
    }

    File file = SD.open(kRecordPath, FILE_WRITE);
    if (!file) {
        deinitMic();
        setError(FailureOrigin::RECORD, "File open failed",
                 "Could not create /record.wav on the SD card.");
        return RecordResult::FAILURE;
    }

    uint8_t wavHeader[kWavHeaderSize];
    generateWavHeader(wavHeader, kRecordDataBytes);
    if (file.write(wavHeader, kWavHeaderSize) != kWavHeaderSize) {
        file.close();
        SD.remove(kRecordPath);
        deinitMic();
        setError(FailureOrigin::RECORD, "Header write failed",
                 "The WAV file header could not be saved.");
        return RecordResult::FAILURE;
    }

    clearFailure();
    gRecordBytesWritten = 0;
    gRecordRms = 0;
    gRecordPeak = 0;
    setState(State::RECORDING);
    redrawScreen();
    gScreenDirty = false;
    gLastUiDrawMs = millis();

    uint32_t lastUiRefreshMs = gLastUiDrawMs;
    int16_t sampleBuffer[kRecordChunkSamples];

    while (gRecordBytesWritten < kRecordDataBytes) {
        size_t bytesRead = 0;
        const esp_err_t readResult = i2s_read(
            kMicPort, sampleBuffer, kRecordChunkBytes, &bytesRead, 100);

        if (readResult != ESP_OK || bytesRead == 0) {
            continue;
        }

        const size_t bytesToWrite = min(bytesRead, static_cast<size_t>(kRecordDataBytes - gRecordBytesWritten));
        const size_t sampleCount = bytesToWrite / sizeof(int16_t);

        for (size_t index = 0; index < sampleCount; ++index) {
            sampleBuffer[index] = applySampleGain(sampleBuffer[index]);
        }

        const size_t bytesWritten = file.write(reinterpret_cast<const uint8_t *>(sampleBuffer), bytesToWrite);
        if (bytesWritten != bytesToWrite) {
            file.close();
            SD.remove(kRecordPath);
            deinitMic();
            setError(FailureOrigin::RECORD, "Write failed",
                     "Audio data could not be fully written to SD.");
            return RecordResult::FAILURE;
        }

        gRecordBytesWritten += bytesWritten;

        if (sampleCount > 0) {
            gRecordRms = computeRms(sampleBuffer, sampleCount);
            if (gRecordRms > gRecordPeak) {
                gRecordPeak = gRecordRms;
            } else {
                gRecordPeak = (gRecordPeak * 31U) / 32U;
            }
        }

        if (userButton.pressed()) {
            file.close();
            SD.remove(kRecordPath);
            deinitMic();
            gRecordBytesWritten = 0;
            gRecordRms = 0;
            gRecordPeak = 0;
            Serial.println(F("[REC] USER key pressed, restarting take."));
            return RecordResult::RESTART;
        }

        const uint32_t now = millis();
        if (now - lastUiRefreshMs >= kUiFrameIntervalMs) {
            markDirty();
            redrawScreen();
            gScreenDirty = false;
            gLastUiDrawMs = now;
            lastUiRefreshMs = now;
        }
    }

    file.close();
    deinitMic();
    refreshSdStats();

    File verify = SD.open(kRecordPath, FILE_READ);
    if (verify) {
        gRecordedFileSize = verify.size();
        verify.close();
    } else {
        gRecordedFileSize = gRecordBytesWritten + kWavHeaderSize;
    }

    gHasRecording = true;
    clearFailure();
    setState(State::READY);
    resetEncoderSelection(0);
    Serial.printf("[REC] Saved %lu bytes to %s\n", gRecordedFileSize, kRecordPath);
    return RecordResult::SUCCESS;
}

void startRecordingWorkflow()
{
    stopPlayback(false);

    while (true) {
        if (!ensureSdMounted()) {
            clearSdInfo();
            setState(State::WAIT_SD);
            return;
        }

        const RecordResult result = recordOnce();
        if (result == RecordResult::RESTART) {
            delay(80);
            continue;
        }
        if (result == RecordResult::NO_SD) {
            clearSdInfo();
            setState(State::WAIT_SD);
            return;
        }
        return;
    }
}

CardState sdCardState()
{
    return gSdMounted ? CardState::PASS : CardState::WAIT;
}

CardState recordCardState()
{
    if (gState == State::RECORDING) {
        return CardState::ACTIVE;
    }
    if (!gSdMounted) {
        return CardState::WAIT;
    }
    if (gFailureOrigin == FailureOrigin::RECORD) {
        return CardState::FAIL;
    }
    return gHasRecording ? CardState::PASS : CardState::WAIT;
}

CardState playCardState()
{
    if (gState == State::PLAYING) {
        return CardState::ACTIVE;
    }
    if (!gSdMounted) {
        return CardState::WAIT;
    }
    if (gFailureOrigin == FailureOrigin::PLAYBACK) {
        return CardState::FAIL;
    }
    return gHasRecording ? CardState::PASS : CardState::WAIT;
}

#include "test_record_audio_ui.h"

void redrawScreen()
{
    deselectSharedSpiDevices();

    if (gCanvasReady) {
        drawUi(canvas);
        canvas.pushSprite(0, 0);
    } else {
        drawUi(tft);
    }

    deselectSharedSpiDevices();
}

void updateEncoderSelection()
{
    if (gState != State::READY && gState != State::PLAYING && gState != State::ERROR) {
        return;
    }

    const long position = encoder.getPosition();
    if (position == gLastEncoderPosition) {
        return;
    }

    gLastEncoderPosition = position;
    long normalized = position % 2L;
    if (normalized < 0) {
        normalized += 2L;
    }

    const uint8_t nextIndex = static_cast<uint8_t>(normalized);
    if (nextIndex != gMenuIndex) {
        gMenuIndex = nextIndex;
        markDirty();
    }
}

void handleEncoderConfirm()
{
    switch (gState) {
    case State::READY:
        if (gMenuIndex == 0U) {
            startPlayback();
        } else {
            startRecordingWorkflow();
        }
        break;

    case State::PLAYING:
        if (gMenuIndex == 0U) {
            stopPlayback(true);
        } else {
            startRecordingWorkflow();
        }
        break;

    case State::ERROR:
        startRecordingWorkflow();
        break;

    case State::WAIT_SD:
    case State::RECORDING:
    default:
        break;
    }
}

void pollInputs()
{
    encoder.tick();
    updateEncoderSelection();

    if (gState != State::RECORDING && userButton.pressed()) {
        Serial.println(F("[REC] USER key pressed, starting a new take."));
        startRecordingWorkflow();
        return;
    }

    if (gState != State::RECORDING && encoderButton.pressed()) {
        handleEncoderConfirm();
    }
}

void updateStateMachine()
{
    if (gState == State::WAIT_SD) {
        const uint32_t now = millis();
        if (now - gLastSdProbeMs >= kSdRetryIntervalMs) {
            gLastSdProbeMs = now;
            if (ensureSdMounted()) {
                Serial.println(F("[SD] Card detected, starting recording."));
                startRecordingWorkflow();
            }
        }
        return;
    }

    if (gState == State::PLAYING) {
        if (audio.isRunning()) {
            audio.loop();
        } else {
            refreshSdStats();
            setState(State::READY);
            resetEncoderSelection(0);
            Serial.println(F("[PLAY] Playback finished."));
        }
    }
}

} // namespace

void setup()
{
    Serial.begin(115200);
    delay(500);

    Serial.println();
    Serial.println(F("T-Embed Record Audio Test"));

    if (!initDisplayPower()) {
        Serial.println(F("[REC] Display power init failed - halting."));
        while (true) {
            delay(1000);
        }
    }

    userButton.begin();
    encoderButton.begin();

    canvas.setColorDepth(16);
    gCanvasReady = (canvas.createSprite(tft.width(), tft.height()) != nullptr);
    if (!gCanvasReady) {
        Serial.println(F("[REC] Sprite allocation failed, using direct TFT redraw."));
    }

    if (!audio.setPinout(BOARD_VOICE_BCLK, BOARD_VOICE_LRCLK, BOARD_VOICE_DIN)) {
        Serial.println(F("[PLAY] Speaker pinout init failed."));
    }
    audio.setVolume(kAudioVolume);

    resetEncoderSelection(0);
    setState(State::WAIT_SD);
    redrawScreen();
    gScreenDirty = false;
    gLastUiDrawMs = millis();
}

void loop()
{
    pollInputs();
    updateStateMachine();

    if (gScreenDirty &&
        (gLastUiDrawMs == 0 || millis() - gLastUiDrawMs >= kUiFrameIntervalMs)) {
        redrawScreen();
        gScreenDirty = false;
        gLastUiDrawMs = millis();
    }

    delay(gState == State::PLAYING ? 2 : 10);
}

void audio_info(const char *info)
{
    Serial.print(F("[AUDIO] "));
    Serial.println(info);
}

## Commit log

2024-03-30 Add Lora and NFC
    [硬件产前测试记录模板_240329.xlsx]
2024-04-02 Resolved conflicts between screen and lora SPI
    [bq25896_test.ino, utilities.h]
2024-04-03 Add Lora mode switch
2024-04-06 Add mono font and battery info screen.
2024-04-10 Add theme switch
2024-04-20 Updata readme
    [硬件产前测试记录模板_240329.xlsx]
2024-05-15 fix：Identify two serial ports; The WIFI interface causes a restart
2024-05-21 feat：Add record 、voice、battery demo
2024-05-22 feat：Added the ability to play music
2024-05-31 perf：Added screen rotation animation
2024-06-07 feat：Add BQ27220
2024-06-14 feat：add shutdown animation
2024-07-06 test：Add test firmware
2024-07-23 test：Fix CC1101 test
2024-07-23 fix：Update firmware
2024-07-23 docs：Update README
2024-07-23 fix：platformio.ini
2024-08-19 fix：Abnormal sleep power consumption
    [factory_test.ino, utilities.h]
2024-08-19 fix：pin change issue
2024-08-20 docs：Update schematic
2024-09-03 fix：compile error
2024-09-11 fix：NFC exception
2024-10-16 fix：Update test firmware
2024-12-11 fix：Add bq2722 reset
2024-12-11 fix：Add missing file
2024-12-25 v1.0-20241225 : Add a charge detection symbol
2025-01-09 Optimize charging parameters Add charging completion identifier. Update firmware;
2025-08-23 [Version]：v1.3-250822
2025-11-07 Add peripheral device test
2025-12-17 Add remarks
    [t_embed-1_pcb_1_1_1.stp]
2026-01-20 Add esp32C5 AT data
    [mfg_nvs.csv]
2026-01-20 add 3D files
    [0-bmq_asm.stp]
2026-03-18 [Version]：v1.4-260318
2026-03-19 [Version]：v1.4-260319
2026-03-30 [Version]：v1.5-260330 Optimize the interfaces of NFC, IR, and NRF24
2026-04-02 [Version]：v1.6-260402 Add the BLE top-level page of factory_test
2026-06-01 Fix pin errors
2026-06-03 add 3D File #76
    [external antenna.stp]
2026-06-23 Move the pin definitions to the top layer
2026-06-23 Add the Battery Chage/Discharge test program
2026-06-25 [Version]：V1.0.0 --- Add a new UI factory program
